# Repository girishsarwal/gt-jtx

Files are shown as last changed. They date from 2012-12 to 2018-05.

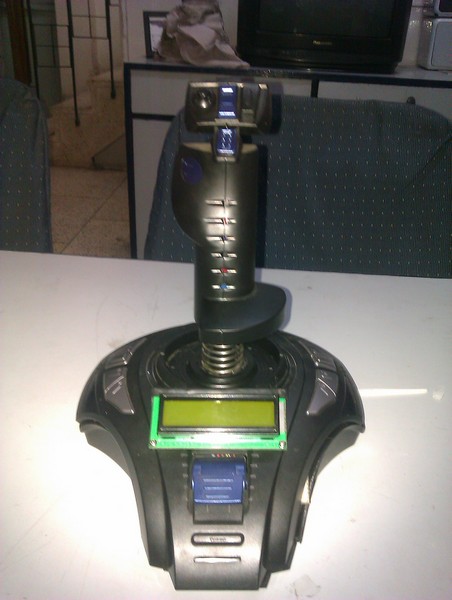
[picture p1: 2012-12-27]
gt-jtx-m8/build-photos/IMAG0161.jpg

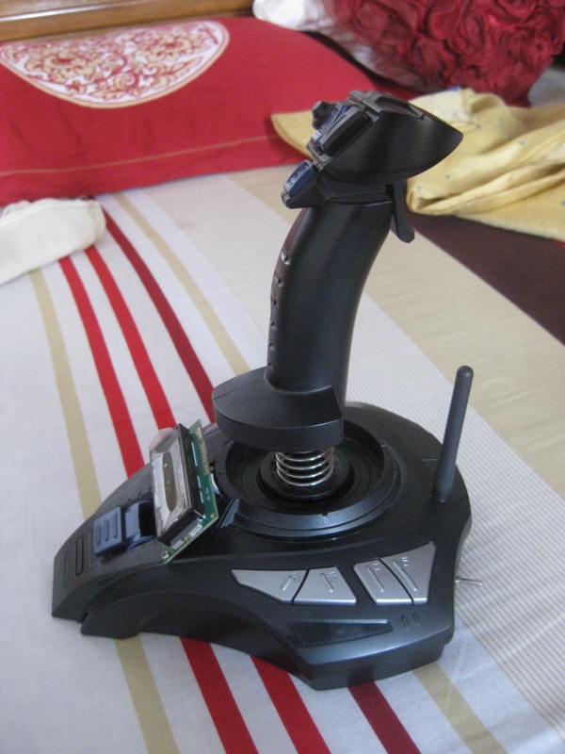
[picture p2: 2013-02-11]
gt-jtx-m8/build-photos/IMG_1433.JPG

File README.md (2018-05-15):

# gt-jtx
What is gt-jtx?
I feel it's cool to control an airplane with a 3d joystick rather than gimbals. It's intuitive and real aircraft pilots (or those trained on MSFS) can appreciate. See Yoke and HOTAS ("Hotass")

After a good amount of self provocation, I embarked on the journey of doing a joystick based 4 analog and 1 digital channels transmitter for controlling Airplanes. Additionally, this system needs to have a basic menu system, settings (Expo/Dr, Rev etc..) and a monitor

# How does it work?
The gt-jtx uses a 3d joystick for controlling an RC airplane. The X axis map to ailerons (roll), Y to Elevator (pitch) and the joystick grip twist/Z axis map to Rudder (Yaw) control. The throttle control has a separate pot on the base of the joystick. Digital push buttons 5-12 on the joystick base are trim switches for the four channels and pressing unique combos on these switches along with power switch navigates through the menu and settings screen.

# Variants
There are three variants of the gt-jtx in order of ease of development

- Arduino Mega - V1.2 available - Open TX
- ATMEGA 8 - V1.0 available - Custom firmware
- ATMEGA 32 - Work under progress

See the wiki for more details

# Disclaimer
I take no responsibility or warranty for any damage to you or your equipment, that may arise out of or is a consequence of using or reproducing any parts or features of the gt-jtx software/hardware system. Everything you do is completely at your own risk and expense.

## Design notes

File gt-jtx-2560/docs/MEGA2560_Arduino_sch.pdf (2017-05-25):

ICSP

# +5V GND

+5V

GND

GND

+5V

GND | GND
47u | 47u GND | GND

GND

GND

GREEN | GND
+5V M7 | GND MC33269D-5.0 MC33269ST-5.0T3

100nGND
100n

100n

+3V3

+5V

+5V

ATMEGA1280-16AU

100n 100n

22p

+5V

GND

100n GND

100n

YELLOW

YELLOW

500mA

+5V

100n GND

YELLOW

GND

100n

FDN340P

LM358D | LM358D GND

100n GND

+5V

100n | +5V

GND

+5V

GND

1u

+5V

ATMEGA8U2-MU

ICSP

+5V

GND

GND

16MHz GND | GND
BLM21 PGB¹⁰¹⁰⁶⁰⁴ | PGB¹⁰¹⁰⁶⁰⁴

16MHz GND
1M

1k

1k

1k

1k

10K

10K 10K

10K

10K

10K

10K

10K

1k1k

1k1k

22R

22R
22R

22R

GND
TS42

1M

16MHz

16MHz

22p 22p

22p 22p GND

GND

GND

27R

27R

1 | 2
3 | 4
5 | 6

ICSP

1

2

3

4

5

6

7

8 | PWML

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
PWMH

PC1 | PC2 | ON D1
1

1

2

2

3

3 | VI 3

1 VO

2

IC2 ADJ

1

IN

3 OUT

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
POWER

C3 | C6

C2

1

2

3

4

5

91 | | 7
92 | ADC0 ADC2 ADC1 ADC3 ADC4 ADC5 ADC6 ADC7 | 6
8 | ADCL

1

2

3

4

5

6

7

8 | COMMUNICATION

(A8)PC0

53

(A9)PC1

54

(A10)PC2

55

(A11)PC3

56

(A12)PC4

57

(A13)PC5

58

(A14)PC6

59

(A15)PC7

60

(AD0)PA0

78

(AD1)PA1

77

(AD2)PA2

76

(AD3)PA3

75

(AD4)PA4

74

(AD5)PA5

73

(AD6)PA6

72

(AD7)PA7

71

(ADC0)PF0

97

(ADC1)PF1

96

(ADC2)PF2

95

(ADC3)PF3

94

(ADC4/TCK)PF4

93

(ADC5/TMS)PF5

(ADC6/TDO)PF6

(ADC7/TDI)PF7

90

(ALE)PG2

70

(CLKO/ICP3/INT7)PE7

9

(ICP1)PD4

47

(MISO/PCINT3)PB3

22
(MOSI/PCINT2)PB2

21

(OC0A/OC1C/PCINT7)PB7

26

(OC0B)PG5

1

(OC1A/PCINT5)PB5

24

(OC1B/PCINT6)PB6

25

(OC2A/PCINT4)PB4

23

(OC3A/AIN1)PE3

5

(OC3B/INT4)PE4

6

(OC3C/INT5)PE5

7

(RD)PG1

52

(RXD0/PCIN8)PE0

2

(RXD1/INT2)PD2

45

(SCK/PCINT1)PB1

20

(SCL/INT0)PD0

43

(SDA/INT1)PD1

44

(SS/PCINT0)PB0

19

(T0)PD7

50
(T1)PD6

49

(T3/INT6)PE6

8

(TOSC1)PG4

29
(TOSC2)PG3

28

(TXD0)PE1

3

(TXD1/INT3)PD3

46

(WR)PG0

51

(XCK0/AIN0)PE2

4

(XCK1)PD5

48

AGND

99 | AREF
98 | AVCC
100

GND

11
32
62
81
PH0(RXD2) 12 | PH1(TXD2) 13 | PH2(XCK2) 14 | PH3(OC4A) 15 | PH4(OC4B) 16 | PH5(OC4C) 17 | PH6(OC2B) 18 | PH7(T4) 27 | PJ0(RXD3/PCINT9) 63 | PJ1(TXD3/PCINT10) 64 | PJ2(XCK3/PCINT11) 65 | PJ3(PCINT12) 66 | PJ4(PCINT13) 67 | PJ5(PCINT14) 68 | PJ6(PCINT15) 69 | PJ7
79 | PK0(ADC8/PCINT16) 89 | PK1(ADC9/PCINT17) 88 | PK2(ADC10/PCINT18) 87 | PK3(ADC11/PCINT19) 86 | PK4(ADC12/PCINT20) 85 | PK5(ADC13/PCINT21) 84 | PK6(ADC14/PCINT22) 83 | PK7(ADC15/PCINT23) 82 | PL0(ICP4) 35 | PL1(ICP5) 36 | PL2(T5) 37 | PL3(OC5A) 38 | PL4(OC5B) 39 | PL5(OC5C) 40 | PL6
41 | PL7

42

RESET

30

VCC

10
31
61
80

XTAL1

34 XTAL2

33

GND GND GND

VCC

VCC

VCC

IC3

C4 C5

1

2

3

4

5

6

7

8 ADCH

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
$1 P$1 P$2 P$2 X2 F1

C9

L

C7

T2

2

3
1

IC5A

6

5
7

IC5B

8 4
C12 C11
1 | 2
3 | 4
5 | 6
7 | 8
9 | 10
11 | 12
13 | 14
15 | 16

XIOH

1 | 2
3 | 4
5 | 6
7 | 8
9 | 10
11 | 12
13 | 14
15 | 16

XIOL

1 | JP1
1 | JP2
1 | JP3
1 | JP4
1 | 2 RESET-EN

C10

(PCINT9/OC1B)PC5

25
(PCINT10)PC4

26

(INT4/ICP1/CLK0)PC7

22
(OC1A/PCINT8)PC6

23

(AIN2/PCINT11)PC2

5

(PCINT5)PB5

19
(T1/PCINT4)PB4

18
(PD0/MISO/PCINT3)PB3

17
(PDI/MOSI/PCINT2)PB2

16
(SCLK/PCINT1)PB1

15
(SS/PCINT0)PB0

14

(CTS/HWB/AIN6/TO/INT7)PD7

13
(RTS/AIN5/INT6)PD6

12
(XCK/AIN4/PCINT12)PD5

11
(INT5/AIN3)PD4

10
(TXD1/INT3)PD3

9
(RXD1/AIN1/INT2)PD2

8
(AIN0/INT1)PD1

7
(OC0B/INT0)PD0

6

GND

3 | VCC
4 | AVCC

32

UVCC

31

XTAL1

1 | XTAL2(PC0) 2 | RESET(PC1/DW) 24

UGND

28

IC4

PAD

EXP

UCAP

27 | D- 30 | D+

29

(PCINT6)PB6

20

(PCINT7/OC0A/OC1C)PB7

21

1 | 2
3 | 4
5 | 6

ICSP1

Y2

## 2 1 UBOOT

L1

Z1Z2

1 2 GROUND

Y1 R1

1 | 8 RN4A
2 | 7 RN4B
3 | 6 RN4C
4 | 5 RN4D

### 1 8 RN5A

2 7 RN5B

3 6 RN5C

4 5 RN5D

1 8 RN1A

2 7 RN1B

3 6 RN1C

4 | 5 RN1D
1 | 8 RN3A
2 | 7 RN3B
3 | 6 RN3C
5 | 4 RN3D
8 | 1 RN2A
2 | 7 RN2B
3 | 6 RN2C
5 | 4 RN2D
3 | 1
4 | 2 RESET

5

R2

2 1Q1

2 1Q2

C14 C15

C16 C17

IN

1 | EN
3 | NC/FB

4 OUT

5 GND

2

R3

R4

+5V
+5V

GND

AREF AREF AREF

RESET

RESET | RESET

RESET

RESET

VIN

VIN

VIN

# M8RXD M8RXD M8TXD

M8TXD

PWRIN

+3V3

+3V3 | +3V3

SDA

SDA

SCL

SCL ADC9 ADC8 ADC10 ADC11 ADC12 ADC13 ADC14 ADC15

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
PB5 PB4

PE5 | PE5 PE4 | PE4 PE3 | PE3 PE1 | PE1

PE1

PE0 | PE0 | PE0

DTR

USBVCC

USBVCC

USBVCC GATE_CMD

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
RXD1 TXD1 RXD2

RXD2

RXD3

RXD3

TXD2

TXD2

TXD3

TXD3

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
## PB0 PG0

PG0

PG1

PG1

PG2

PG2

PD7 PD7

PA0 | PA0 PA1 | PA1 PA2 | PA2 PA3 | PA3 PA4 | PA4 PA5 | PA5 PA6 | PA6 PA7 | PA7
PL0 PL0 | PL1 PL1 | PL2 PL2 | PL3 PL3 | PL4 PL4 | PL5 PL5 | PL6 PL6 | PL7 PL7

PB7

VUCAP

RD-

RD-

RD+

RD+

RESET2

RESET2 | MISO2

MISO2

MOSI2

MOSI2

SCK2

SCK2

XVCC

RXL TXL

# D- D+ UGND

UGND

USHIELD

XTAL2

XTAL2 XTAL1

XTAL1

XT2

## XT2 XT1

XT1

XTAL1R

XT1R

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
(SCK)

(MISO)
(MOSI)

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
(TX0)
(RX0)

51

53 | 52

pwm
pwm

pwm

pwm
pwm

(MISO)

(SCK)

(MOSI)

(SS)
(MOSI)

(SCK)
(MISO)
23 | 22
25 | 24
27 | 26
29 | 28
| 30

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
USB boot En

# Arduino Mega 2560 Reference Design

TM

Reference Designs ARE PROVIDED "AS IS" AND "WITH ALL FAULTS". Arduino DISCLAIMS ALL OTHER WARRANTIES, EXPRESS OR IMPLIED, Arduino may make changes to specifications and product descriptions at any time, without notice. The Customer must not REGARDING PRODUCTS, INCLUDING BUT NOT LIMITED TO, ANY IMPLIED WARRANTIES OF MERCHANTABILITY OR FITNESS FOR A PARTICULAR PURPOSE

rely on the absence or characteristics of any features or instructions marked "reserved" or "undefined." Arduino reserves
these for future definition and shall have no responsibility whatsoever for conflicts or incompatibilities arising from future changes to them. The product information on the Web Site or Materials is subject to change without notice. Do not finalize a design with this information.

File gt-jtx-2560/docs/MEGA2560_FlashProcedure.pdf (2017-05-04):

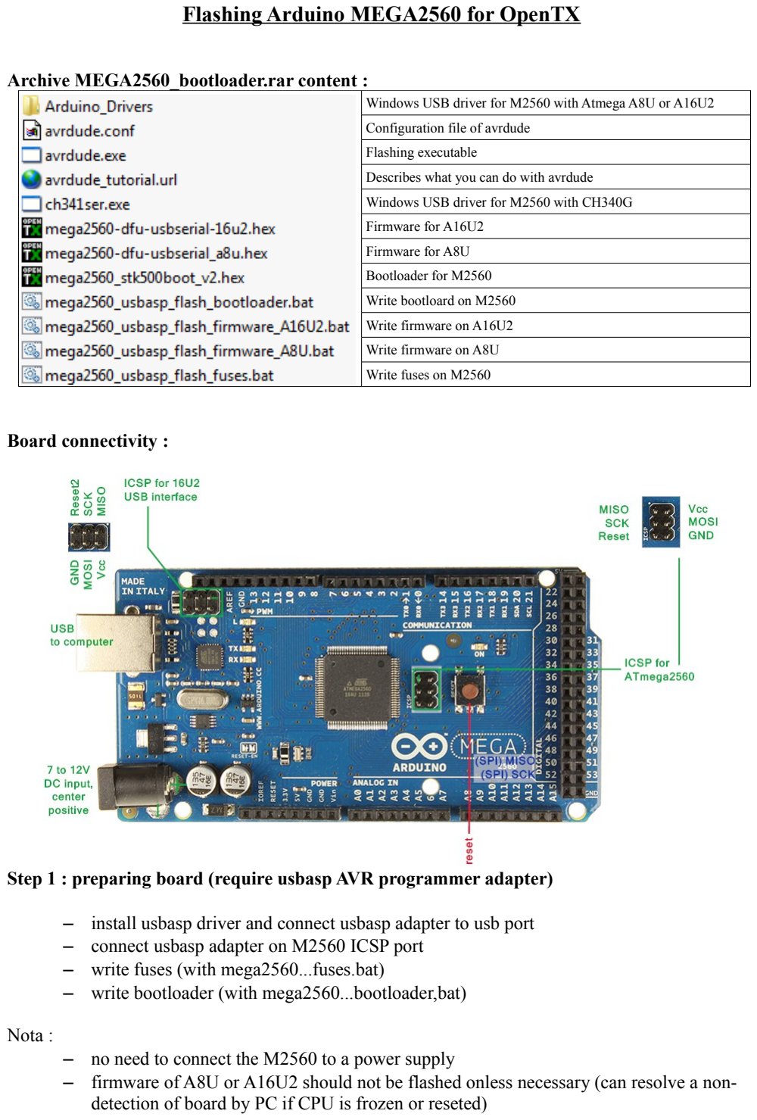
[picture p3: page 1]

Flashing Arduino MEGA2560 for OpenTX

Archive MEGA2560_bootloader.rar content :
Windows USB driver for M2560 with Atmega A8U or A16U2 Configuration file of avrdude
Flashing executable
Describes what you can do with avrdude
Windows USB driver for M2560 with CH340G Firmware for A16U2
Firmware for A8U
Bootloader for M2560
Write bootloard on M2560
Write firmware on A16U2
Write firmware on A8U
Write fuses on M2560

Board connectivity :

Step 1 : preparing board (require usbasp AVR programmer adapter)

– install usbasp driver and connect usbasp adapter to usb port – connect usbasp adapter on M2560 ICSP port
– write fuses (with mega2560...fuses.bat)
– write bootloader (with mega2560...bootloader,bat)

Nota :
– no need to connect the M2560 to a power supply
– firmware of A8U or A16U2 should not be flashed onless necessary (can resolve a nondetection of board by PC if CPU is frozen or reseted)

Step 2 : connecting board to USB
CH340G board | A8U or A16U2 board
- execute « ch341ser.exe » to install driver • connect M2560 on one USB port • Windows should automatically configure driver | • connect M2560 on one USB port • Windows opens an installation panel • choose manually the driver « arduino.inf » in the folder « Arduino_Drivers » provided

– verify on Windows device management (direct access : devmgmt.msc) if device works, and witch com is used (com1, com2, etc.)

Step 3 : setting Companion communication

– launch OpenTX Companion 2.1
– open the « Configure communications » menu
– set the following parameters (with the right com) :

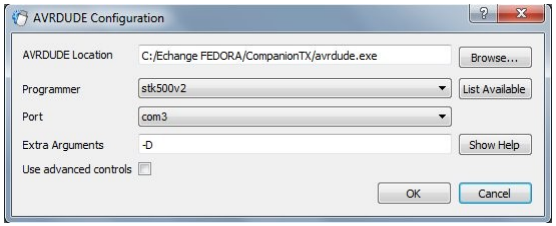
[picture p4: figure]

– A8U or A16U2 board : for each firmware or eeprom access (read or flash), M2560 must be reset just before (press reset button is board is already connected, or simply plug the board on USB)
– CH340G board : USB communication remains open after startup, no need to reset
Step 3 : setting Companion Radio Profile and and Application Settings

– go to the « Settings » menu, click « Settings »
– select « Radio Profile » tab
– check LCD, language and options needed :

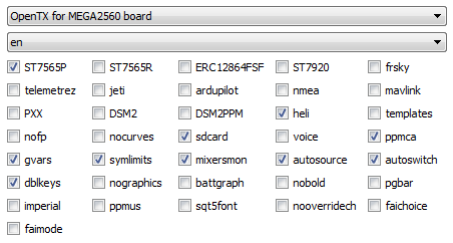
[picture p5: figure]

– select « Application Settings » tab
– open a folder for eeprom backup (don't check « Enable auto... » for the moment)
Step 4 : first flash with Companion

– go to « File » menu, click « Download »
– download firmware
– go to « Read/Write » menu, click « Write Firmware to Radio »
– load the downloaded firmware
– uncheck (for the moment) « Backup and restore Models ans Settings »

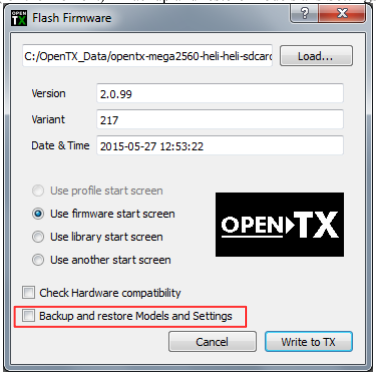
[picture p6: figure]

– write to TX...
– unplug the radio form USB port
– run the radio or plug it to usb port
– OpenTX should start and launch the init sequence (formatting eeprom then calibrate the sticks)
– enjoy... :)

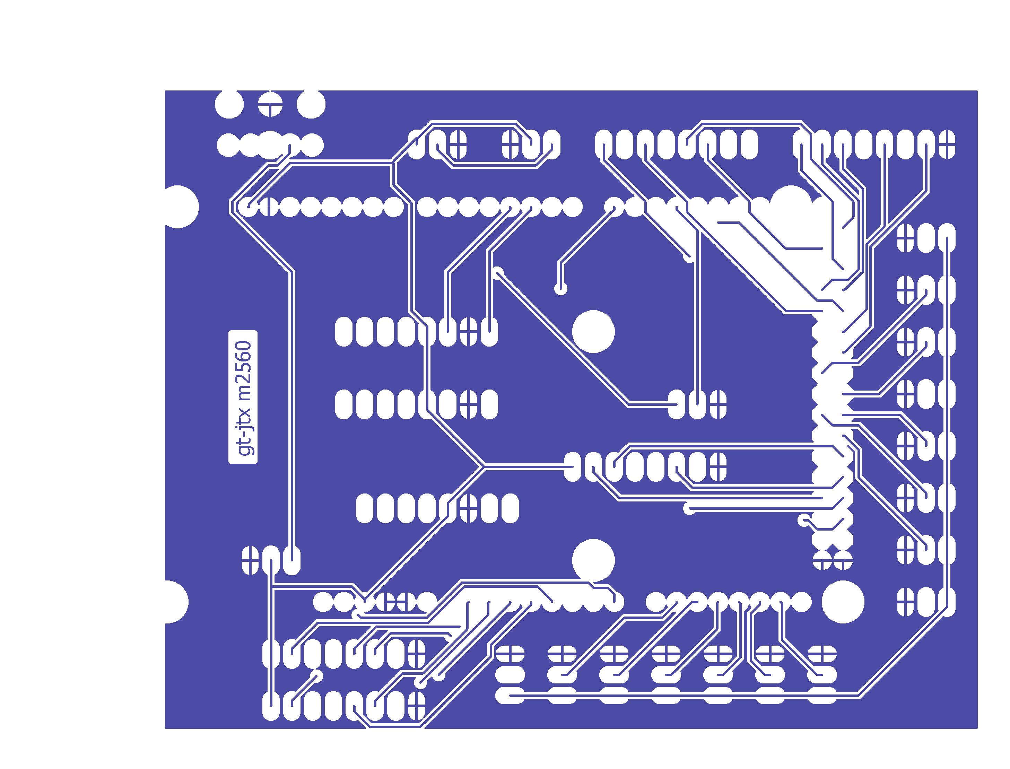
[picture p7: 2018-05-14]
gt-jtx-2560/hardware/bottom.png

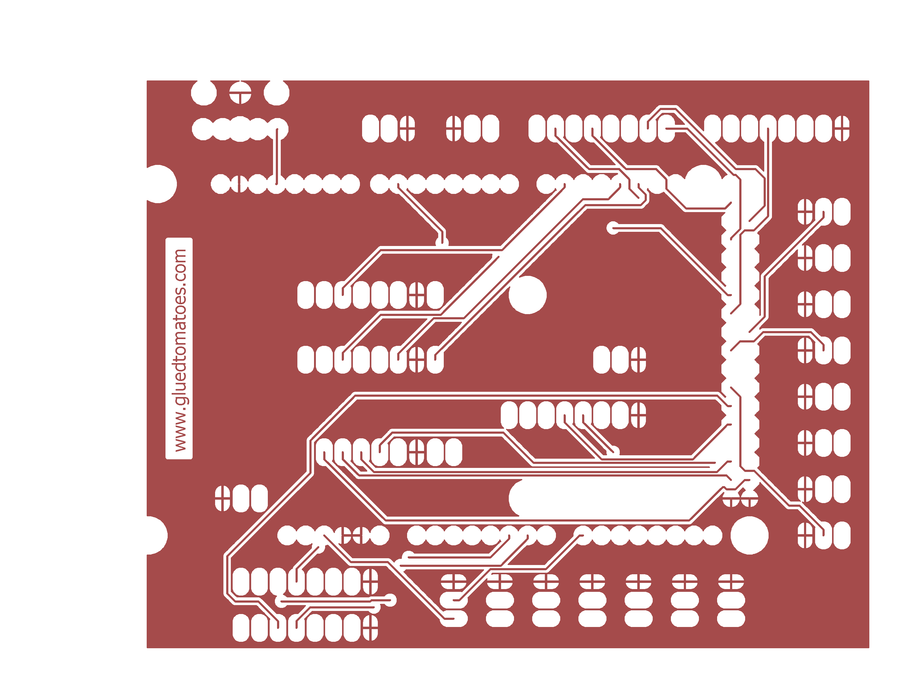
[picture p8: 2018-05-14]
gt-jtx-2560/hardware/top.png

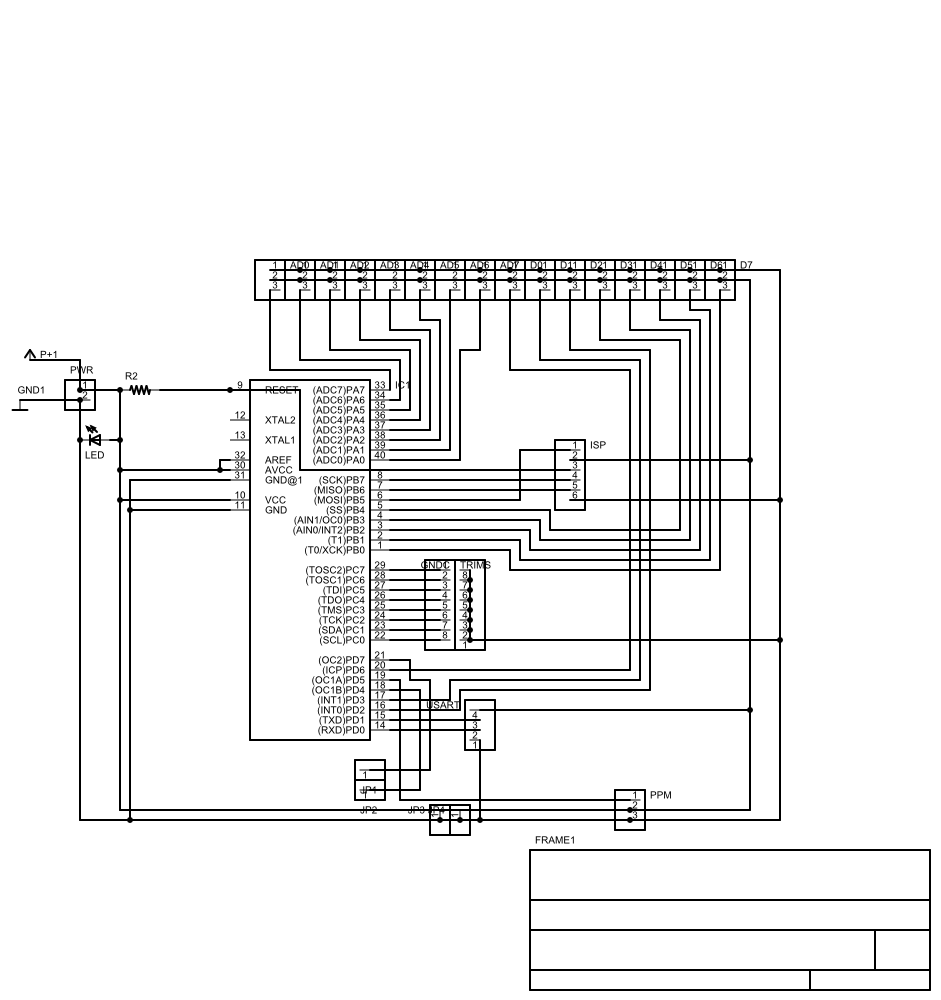
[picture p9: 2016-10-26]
gt-jtx-m32/hardware/gt-jtx-m32-ver1.0.png

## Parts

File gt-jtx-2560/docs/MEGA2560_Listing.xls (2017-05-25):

Board | Label | Qty | Manufacturer | Part Number | Description | Case | Implantation | Side | Points | Total pts | Comment
- | - | 1 | - | - | 2 mm plywood 250 x 500 mm | - | - | - | - | - | Prefere marine or aircraft plywood
- | - | 1 | Funduino, SaintSmart | MEGA2560 | Arduino Mega2560 clone (http://www.ebay.fr/itm/291335218312) | - | - | - | - | - | Main board (prefer with CH340G serial driver) (http://www.ebay.fr/itm/151303481964)
- | - | 2 | Samsung, Panasonic, etc. | - | 18650 round Li-Ion with PCB (http://fr.aliexpress.com/item/-/32257563308.html) | - | - | - | - | - | 2400 to 3400 mAh
- | - | 1 | - | - | HF module (2.4 GHz, 433 MHz, etc.) | - | - | - | - | - | PPM positive or negative shift, up to 16 channels + telemetry
- | - | 0 to 1 | - | - | RS232 to TTL converter (MAX3232) (http://www.ebay.fr/itm/221484714177) | - | - | - | - | - | For FrSky telemetry (if no "direct TTL" modification)
- | - | 1 | - | - | USBASP programmer (http://www.ebay.com/sch/i.html?_from=R40&_nkw=usbasp&_sacat=0) | - | - | - | - | - | For bootloader and fuses flash
- | - | 1 | Artronic | 128064MN19-FHW | LCD 128x64 ST7565R (http://www.ebay.fr/itm/321632747032) | - | - | - | - | - | LCD (large, 3.3V, to use with M2560-1 board)
- | - | 1 | Zolen | ZLE12864A | LCD 128x64 ST7565P (http://fr.aliexpress.com/item/4pcs-New-12864-128x64-Graphic-LCD-Display-module-ST7565P-Free-Shipping/1383335383.html) | - | - | - | - | - | LCD (small, 5V)
- | - | 1 | Turnigy | 9171000250 | 9XR gimbal left (http://www.hobbyking.com/hobbyking/store/__39505__transmitter_gimbal_set_left_turnigy_9xr_transmitter_mode_1.html) | - | - | - | - | - | Gimbal basic (direct connection on MEGA)
- | - | 1 | Turnigy | 9171000248 | 9XR gimbal right (http://www.hobbyking.com/hobbyking/store/__39503__Transmitter_Gimbal_Set_Right_Turnigy_9XR_Transmitter_Mode_1.html) | - | - | - | - | - | Gimbal basic (direct connection on MEGA)
- | - | 2 | Hitec | - | Aurora9 gimbal (http://www.robotshop.com/en/axis-joystick-gim.html) | - | - | - | - | - | Gimbal option (to use with M2560-5 board)
 | - | 0 to 2 | - | - | PS2 gimbal (http://www.aliexpress.com/item/Free-Shipping-20PCS-LOT-Dual-axis-XY-Joystick-Module-For-Arduino-ps2-Joystick-Module/1882818018.html) | - | - | - | - | - | Gimbal option
- | - | 1 | Turnigy | 9171000045 | M3 sticks pair (http://www.hobbyking.com/hobbyking/store/__23754__Alloy_Anti_Slip_TX_Control_Sticks_Short_Futaba_TX_.html) | - | - | - | - | - | Fit basic or option gimbal
- | - | 0 to 1 | - | - | on-off-on switch | - | - | - | - | - | ID0/1/2 switch
- | - | 0 to 5 | - | - | off-on switch | - | - | - | - | - | DR_e, DR_a, DR_r, ThCut, Gear switches
- | - | 0 to 1 | - | - | off-(on) switch | - | - | - | - | - | TRN (momentary, classic switch)
- | - | 0 to 1 | APEM | MJTP1230 | SPST tactile switch | - | - | - | - | - | TRN (momentary, small swtich), or other(s) switch(es) with T flip-flop virtual switch
- | - | 1 | ALPS | SKQUAAA010 | 4 way navigation switch | - | - | - | - | - | 4 way navigation (if no scroll navigation with M2560-1&2 boards)
- | - | 0 or 2 | APEM | MJTP1230 | SPST tactile switch | - | - | - | - | - | OK/ESC buttons (if no scroll navigation with M2560-1&2 boards)
- | - | 3 | - | - | JST BEC female connector plug | - | - | - | - | - | Charge or external supply connecteur + internal power wiring
- | - | 1 | - | - | JST BEC male connector plug | - | - | - | - | - | Internal power wiring
- | SW1 | 1 | Multicomp | R13-548B-05-BB | SPST push-button | - | - | - | - | - | Main power swtitch (basic)
- | SW1 | 1 | - | - | SPST metal + led push-button (http://www.ebay.fr/sch/i.html?_from=R40&_sacat=0&_nkw=metal+led+switch&_sop=15) | - | - | - | - | - | Main power swtitch (option)
- | - | 0.5 m | - | - | 28 or 30 AWG flap ribbon cable, 20 wires | - | - | - | - | - | LCD, switches and rotary encoders wiring
- | - | 1 | DB Products | PK-21N30-WQ | Piezoelectronic buzzer | - | - | - | - | - | Buzzer with built-in drive circuit
- | - | 0 to 1 | - | - | Mini SD-Card socket for Arduino (http://www.ebay.fr/itm/221485468743) | - | - | - | - | - | Option
- | - | 0 to 1 | - | - | Real Time Clock (http://www.ebay.fr/itm/251730989006) | - | - | - | - | - | Option
M2560-1_LCD | Q1 | 1 | ON Semiconductor | MMFT960T1 | 300 mA 60 Volts N−Channel MOSFET | SOT-223 | SMD | Top | 4 | 4
M2560-1_LCD | U3 | 1 | Microchip | MCP1826S3302 | 3.3V 1A Low drop positive regulator | SOT-223 | SMD | Top | 4 | 4
M2560-1_LCD | R4 | 14 | - | - | 5.1 Kohms 1% resistor | 1206 | SMD | Top | 2 | 28
M2560-1_LCD | R6 | 14 | - | - | 10 Kohms 1% resistor | 1206 | SMD | Top | 2 | 28
M2560-1_LCD | C1 | 2 | - | - | 100 nF 10% 63 V Capacitor X7R | 1206 | SMD | Top | 2 | 4
M2560-2_RotEnc1 | - | 1 | C&K | TSWB-3N-CB111 LFS | 4 ways navigation switch + scroll + pushbutton | - | Through hole | Bottom | 9 | 9 | Rotary encoder 1 & navigation (arrows + Menu)
M2560-2_RotEnc1 | R1 | 7 | - | - | 200 ohms 1% resistor | 1206 | SMD | Top | 2 | 14
M2560-2_RotEnc1 | R4 | 2 | - | - | 5.1 Kohms 1% resistor | 1206 | SMD | Top | 2 | 4
M2560-2_RotEnc1 | C1 | 7 | - | - | 100 nF 10% 63 V Capacitor X7R | 1206 | SMD | Top | 2 | 14
M2560-3_RotEnc2 | - | 1 | C&K | TSWA-3N-CB11 LFS | Scroll + pushbutton | - | Through hole | Bottom | 4 | 4 | Rotary encoder 2 & navigation (Esc) or alone rotary (Rot_x + Push_x)
M2560-3_RotEnc2 | R1 | 3 | - | - | 200 ohms 1% resistor | 1206 | SMD | Top | 2 | 6
M2560-3_RotEnc2 | R4 | 2 | - | - | 5.1 Kohms 1% resistor | 1206 | SMD | Top | 2 | 4
M2560-3_RotEnc2 | C1 | 3 | - | - | 100 nF 10% 63 V Capacitor X7R | 1206 | SMD | Top | 2 | 6
M2560-4_Trim&switches | - | 2 | ALPSS | SKQUAAA01 | 4 ways navigation swtich | - | Through hole | Bottom | 6 | 12
M2560-4_Trim&switches | R1 | 8 | - | - | 200 ohms 1% resistor | 1206 | SMD | Top | 2 | 16
M2560-4_Trim&switches | C1 | 8 | - | - | 100 nF 10% 63 V Capacitor X7R | 1206 | SMD | Top | 2 | 16
M2560-5_Sticks(basic) | - | 4 | TE Connectivity | 292161-3 | 2 mm 3 pins connector header | - | Through hole | Bottom | 3 | 12
M2560-5_Sticks(basic) | - | 1 | - | - | 2.54 mm connector header | - | Through hole | Top | 4 | 4 | 4 pins
M2560-5_Sticks(basic) | U2 | 1 | Microchip | MCP6004 | Low-Power Op Amp | SOIC-14 | SMC | Top | 14 | 14
M2560-5_Sticks(basic) | R2 | 4 | - | - | 2.2 Kohms 1% resistor | 1206 | SMD | Top | 2 | 8
M2560-5_Sticks(basic) | R6 | 8 | - | - | 10 Kohms 1% resistor | 1206 | SMD | Top | 2 | 16
M2560-5_Sticks(full) | - | 4 | TE Connectivity | 292161-3 | 2 mm 3 pins connector header | - | Through hole | Bottom | 3 | 12
M2560-5_Sticks(full) | - | 1 | - | - | 2.54 mm connector header | - | Through hole | Top | 4 | 4 | 21 pins
M2560-5_Sticks(full) | U2 | 1 | Microchip | MCP6004 | Low-Power Op Amp | SOIC-14 | SMC | Top | 14 | 14
M2560-5_Sticks(full) | R2 | 4 | - | - | 2.2 Kohms 1% resistor | 1206 | SMD | Top | 2 | 8
M2560-5_Sticks(full) | R3 | 1 | - | - | 2.7 Kohms 1% resistor | 1206 | SMD | Top | 2 | 2
M2560-5_Sticks(full) | R4 | 1 | - | - | 5.1 Kohms 1% resistor | 1206 | SMD | Top | 2 | 2
M2560-5_Sticks(full) | R6 | 8 | - | - | 10 Kohms 1% resistor | 1206 | SMD | Top | 2 | 16
M2560-6_PPM&Power | - | 1 | - | - | 2.54 mm connector header | - | Through hole | Bottom | 4 | 4 | 33 pins
M2560-6_PPM&Power | U1 | 1 | On Semiconductor | MC14066B | Quad multiplexer | SOIC-14 | SMD | Top | 14 | 14 | Trainer port selector (in / out)
M2560-6_PPM&Power | Q1 | 1 | ON Semiconductor | MMFT960T1 | 300 mA 60 Volts N−Channel MOSFET | SOT-223 | SMD | Top | 4 | 4
M2560-6_PPM&Power | Q2 | 1 | Fairchild Semicon. | NDT2955 | 2.5 A 60 Volts P−Channel MOSFET | SOT-223 | SMD | Top | 4 | 4
M2560-6_PPM&Power | D1 | 4 | MCC | MBR0520LT1G | 0.5 A 20 V low drop Schottky | SOD-123 | SMD | Top | 2 | 8
M2560-6_PPM&Power | R1 | 1 | - | - | 200 ohms 1% resistor | 1206 | SMD | Top | 2 | 2
M2560-6_PPM&Power | R3 | 1 | - | - | 2.7 Kohms 1% resistor | 1206 | SMD | Top | 2 | 2
M2560-6_PPM&Power | R4 | 5 | - | - | 5.1 Kohms 1% resistor | 1206 | SMD | Top | 2 | 10
M2560-6_PPM&Power | R5 | 2 | - | - | 6.8 Kohms 1% resistor | 1206 | SMD | Top | 2 | 4
M2560-6_PPM&Power | R6 | 2 | - | - | 10 Kohms 1% resistor | 1206 | SMD | Top | 2 | 4
M2560-6_PPM&Power | R7 | 2 | - | - | 100 Kohms 1% resistor | 1206 | SMD | Top | 2 | 4
M2560-6_PPM&Power | C1 | 1 | - | - | 100 nF 10% 63 V Capacitor X7R | 1206 | SMD | Top | 2 | 2
M2560-6_PPM&Power | SW2 | 1 | CUI Inc | MD-40SV | Mini DIN 4 pins socket | - | - | - | - | - | Trainer port
M2560-6_PPM&Power | SW2 | 1 | CUI Inc | MD-40 | Mini DIN 4 pins plug | - | - | - | - | - | Trainer port

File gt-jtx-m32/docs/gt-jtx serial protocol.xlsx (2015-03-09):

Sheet: Sheet1
SYNC | PID | SIZE | PAYLOAD

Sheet: Sheet2
Data Signal
OpCode | Description | Data |  | Result
0x00 | Error |  | 8 x 1
0x01 | Frame Lengths |  | 16 x 2
0x02 | Servo Signal Timing |  | 16 x 2
0x03 | Calibration Data Upper |  | 16 x 14
0x04 | Calibration Data Lower |  | 16 x 14
0x05
0x06
0x07
0x08
0x09
0x10 | Pot Data |  | 16 x 14
0x11 | Trim Data |  | 16 x 14
0x12 | Ch Reverse Data |  | 1 x 14
0x13 | Expo Data |  | 16 x 14
0x14 | D/R Data |  | 16 x 14
0x15 | Offset Data |  | 8 x 14
0x16
0x17
0x18
0x19
0x20
0x21
0x22
0x23
0x24
0x25
0x26
0x27
0x28
0x29
0x30
0x31
0x32
0x33
0x34
0x35
0x36
0x37
0x38
0x39
0x40

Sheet: SPI Protocol for UI comms
 | 15 | 14 | 13 | 12 | 11 | 10 | 9 | 8 | 7 | 6 | 5 | 4 | 3 | 2 | 1 | 0
OpCode | Data0 |  |  |  |  |  |  |  | Data1 |  |  |  |  |  |  |  | Result | Menmonic | Description | Comment | General Instructions
0x00 | X |  |  |  |  |  |  |  | X |  |  |  |  |  |  |  | X | NOP | Nop |  | Each SPI Command sends 4 bytes SPI xchange
0x01 | Ch# |  |  |  | X | X | X | X | Amount |  |  |  |  |  |  |  | X | SETTUP | SetTrimUp | Amount is clamped to 200 | the first byte is the opcode
0x02 | Ch# |  |  |  | X | X | X | X | Amount |  |  |  |  |  |  |  | X | SETTDN | SetTrimDn | Amount is clamped to 200 | The second and third byte together form the data for the instruction
0x03 | Ch# |  |  |  | X | X | X | X | Result-HiByte |  |  |  |  |  |  |  | Result-LoByte | GETT | Get Trim | Gets the trim in Amount | The final byte is always a NOP to get the lower byte of the result
0x04 | Ch# |  |  |  | B | X | X | X | X | X | X | X | X | X | X | X | X | SETREV | SetReverse | B=1(REV); B=0(NOR)
0x05 | Ch# |  |  |  | B | X | X | X | Result-HiByte |  |  |  |  |  |  |  | Result-LoByte | GETREV | GetReverse | B=1(REV); B=0(NOR) | Bytes | OpCode | Data0 | Data1 | Result
0x06 | Ch# |  |  |  | X | X | Amount |  |  |  |  |  |  |  |  |  | X | SCUP | SetCalibrationUpper |  | SPI Sent | Opcode | Data0 | Data1 | NOP
0x07 | Ch# |  |  |  | X | X |  |  | Result-HiByte |  |  |  |  |  |  |  | Result-LoByte | GCUP | GetCalibrationUpper |  | SPI Received | NOP | Opcode | Data0 | Data1
0x08 | Ch# |  |  |  | X | X | Amount |  |  |  |  |  |  |  |  |  | X | SCDN | SetCalibrationLower
0x09 | Ch# |  |  |  | X | X |  |  | Result-HiByte |  |  |  |  |  |  |  | Result-LoByte | GCDN | GetCalibrationLower
0x0A | Amount |  |  |  |  |  |  |  |  |  |  |  |  |  |  |  | X | SPPMLEN | SetPPMFrameTotalLength | Amount is in ms
0x0B |  |  |  |  |  |  |  |  | Result-HiByte |  |  |  |  |  |  |  | Result-LoByte | GPPMLEN | GetPPMFrameTotalLength | Amount is in ms
0x0C | Amount |  |  |  |  |  |  |  |  |  |  |  |  |  |  |  | X | SPPMICL | SetPPMFrameInterChannelLength | Amount is in us
0x0D |  |  |  |  |  |  |  |  | Result-HiByte |  |  |  |  |  |  |  | Result-LoByte | GPPMICL | GetPPMFrameInterChannelLength | Amount is in us
0x0E | B | Amount |  |  |  |  |  |  |  |  |  |  |  |  |  |  | X | SSTIM | SetServoTiming | B=0(Lower);B=1(Upper)
0x0F | B |  |  |  |  |  |  |  | Result-HiByte |  |  |  |  |  |  |  | Result-LoByte | GSTIM | GetServoTiming | B=0(Lower);B=1(Upper)
0x10 | Ch# |  |  |  |  |  |  |  | Result-HiByte |  |  |  |  |  |  |  | Result-LoByte | GCV | GetChannelValue

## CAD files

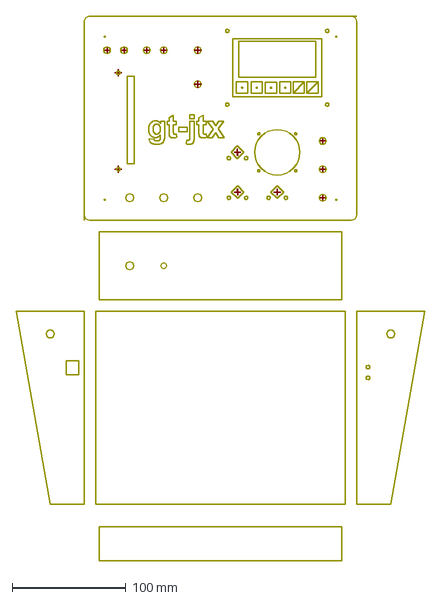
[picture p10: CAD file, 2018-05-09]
gt-jtx-2560/case/gt-jtx-2560.dxf
360.0 x 480.0 mm

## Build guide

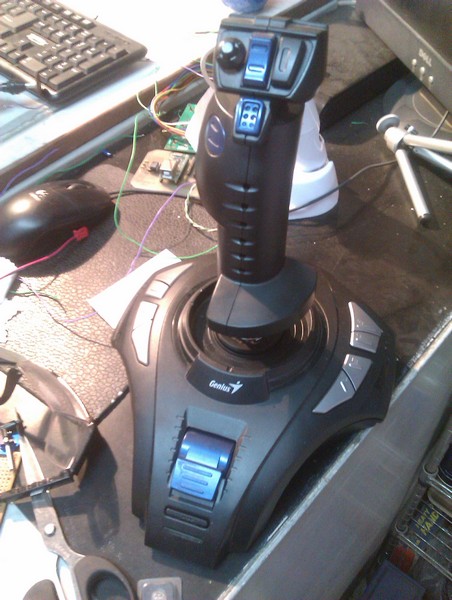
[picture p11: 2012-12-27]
gt-jtx-m8/build-photos/IMAG0158.jpg

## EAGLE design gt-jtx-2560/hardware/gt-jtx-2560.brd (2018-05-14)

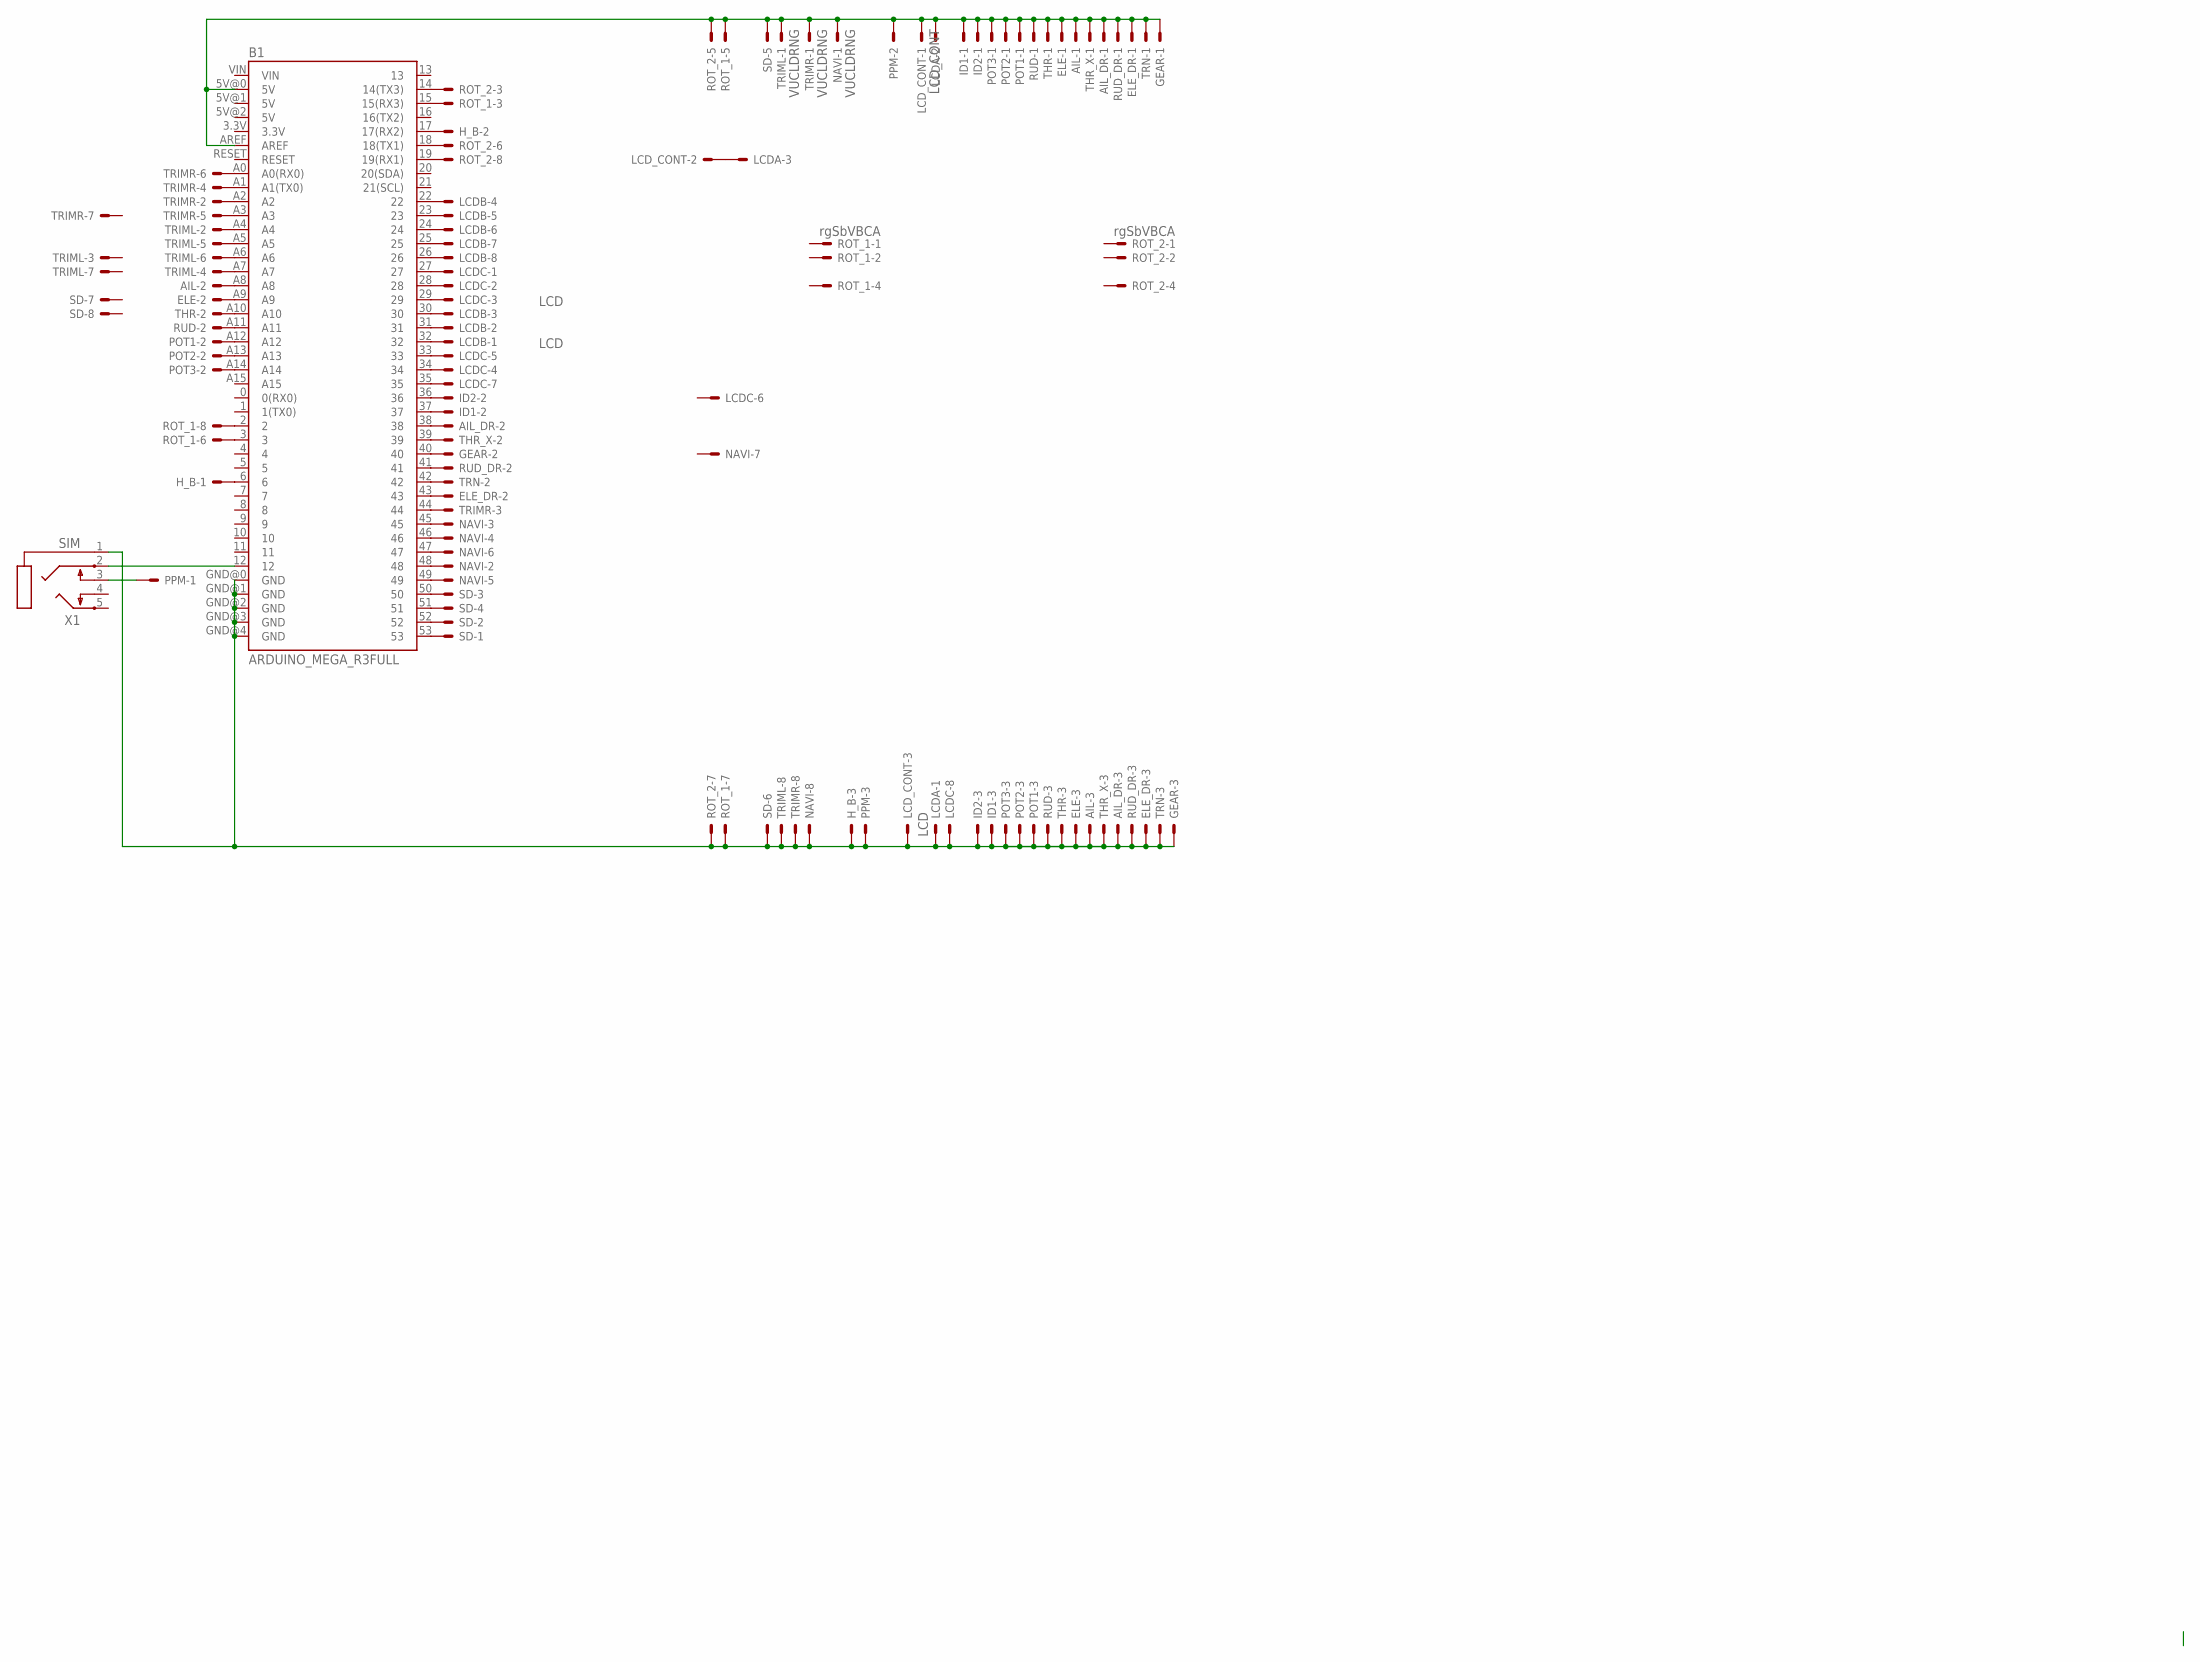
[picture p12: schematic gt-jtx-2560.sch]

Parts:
AIL: JST-XH-03-PIN-LONG-PAD; JST-XH-03-PACKAGE-LONG-PAD
AIL_DR: JST-XH-03-PIN-LONG-PAD; JST-XH-03-PACKAGE-LONG-PAD
B1: ARDUINO_MEGA_R3FULL; ARDUINO_MEGA
ELE: JST-XH-03-PIN-LONG-PAD; JST-XH-03-PACKAGE-LONG-PAD
ELE_DR: JST-XH-03-PIN-LONG-PAD; JST-XH-03-PACKAGE-LONG-PAD
GEAR: JST-XH-03-PIN-LONG-PAD; JST-XH-03-PACKAGE-LONG-PAD
H_B: JST-XH-03-PIN-LONG-PAD; JST-XH-03-PACKAGE-LONG-PAD
ID1, ID2: JST-XH-03-PIN-LONG-PAD; JST-XH-03-PACKAGE-LONG-PAD
LCDA: LCD; JST-XH-03-PACKAGE-LONG-PAD
LCDB: LCD; JST-XH-08-PACKAGE-LONG-PAD
LCDC: LCD; JST-XH-08-PACKAGE-LONG-PAD
LCD_CONT: LCD_CONT; JST-XH-03-PACKAGE-LONG-PAD
NAVI: VUCLDRNG; JST-XH-08-PACKAGE-LONG-PAD
POT1, POT2, POT3: JST-XH-03-PIN-LONG-PAD; JST-XH-03-PACKAGE-LONG-PAD
PPM: JST-XH-03-PIN-LONG-PAD; JST-XH-03-PACKAGE-LONG-PAD
ROT_1, ROT_2: rgSbVBCA; JST-XH-08-PACKAGE-LONG-PAD
RUD: JST-XH-03-PIN-LONG-PAD; JST-XH-03-PACKAGE-LONG-PAD
RUD_DR: JST-XH-03-PIN-LONG-PAD; JST-XH-03-PACKAGE-LONG-PAD
SD: JST-XH-08-PIN-LONG-PAD; JST-XH-08-PACKAGE-LONG-PAD
THR: JST-XH-03-PIN-LONG-PAD; JST-XH-03-PACKAGE-LONG-PAD
THR_X: JST-XH-03-PIN-LONG-PAD; JST-XH-03-PACKAGE-LONG-PAD
TRIML: VUCLDRNG; JST-XH-08-PACKAGE-LONG-PAD
TRIMR: VUCLDRNG; JST-XH-08-PACKAGE-LONG-PAD
TRN: JST-XH-03-PIN-LONG-PAD; JST-XH-03-PACKAGE-LONG-PAD
X1: SIM; STX3100

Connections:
GND: AIL.3, AIL_DR.3, B1.GND@0 (GND), B1.GND@1 (GND), B1.GND@2 (GND), B1.GND@3 (GND), B1.GND@4 (GND), ELE.3, ELE_DR.3, GEAR.3, H_B.3, ID1.3, ID2.3, LCDA.1, LCDC.8, LCD_CONT.3, NAVI.8, POT1.3, POT2.3, POT3.3, PPM.3, ROT_1.7, ROT_2.7, RUD.3, RUD_DR.3, SD.6, THR.3, THR_X.3, TRIML.8, TRIMR.8, TRN.3, X1.1
unnamed: B1.22, LCDB.4
unnamed: B1.23, LCDB.5
unnamed: B1.24, LCDB.6
unnamed: B1.25, LCDB.7
unnamed: B1.26, LCDB.8
unnamed: B1.27, LCDC.1
unnamed: B1.28, LCDC.2
unnamed: B1.29, LCDC.3
unnamed: B1.48, NAVI.2
unnamed: B1.45, NAVI.3
unnamed: B1.46, NAVI.4
unnamed: B1.49, NAVI.5
unnamed: B1.47, NAVI.6
unnamed: B1.A2, TRIMR.2
unnamed: B1.A7, TRIML.4
unnamed: B1.53, SD.1
unnamed: B1.A5, TRIML.5
unnamed: B1.44, TRIMR.3
unnamed: AIL.2, B1.A8
unnamed: B1.A9, ELE.2
unnamed: B1.A10, THR.2
unnamed: B1.A11, RUD.2
unnamed: B1.A12, POT1.2
unnamed: B1.A13, POT2.2
unnamed: B1.A14, POT3.2
unnamed: B1.52, SD.2
unnamed: B1.A1 (A1(TX0)), TRIMR.4
unnamed: B1.A3, TRIMR.5
unnamed: B1.50, SD.3
unnamed: B1.51, SD.4
unnamed: B1.15 (15(RX3)), ROT_1.3
unnamed: B1.6, H_B.1
unnamed: B1.39, THR_X.2
unnamed: B1.41, RUD_DR.2
unnamed: B1.43, ELE_DR.2
unnamed: AIL_DR.2, B1.38
unnamed: B1.42, TRN.2
unnamed: B1.40, GEAR.2
unnamed: B1.12, X1.2
unnamed: B1.17 (17(RX2)), H_B.2
unnamed: B1.A0 (A0(RX0)), TRIMR.6
unnamed: B1.30, LCDB.3
unnamed: B1.31, LCDB.2
unnamed: B1.A6, TRIML.6
unnamed: B1.A4, TRIML.2
unnamed: B1.14 (14(TX3)), ROT_2.3
unnamed: B1.2, ROT_1.8
unnamed: B1.3, ROT_1.6
unnamed: B1.19 (19(RX1)), ROT_2.8
unnamed: B1.18 (18(TX1)), ROT_2.6
unnamed: B1.32, LCDB.1
unnamed: B1.34, LCDC.4
unnamed: B1.33, LCDC.5
unnamed: B1.35, LCDC.7
unnamed: LCDA.3, LCD_CONT.2
unnamed: PPM.1, X1.3
unnamed: B1.36, ID2.2
unnamed: B1.37, ID1.2
VCC: AIL.1, AIL_DR.1, B1.5V@0 (5V), B1.AREF, ELE.1, ELE_DR.1, GEAR.1, ID1.1, ID2.1, LCDA.2, LCD_CONT.1, NAVI.1, POT1.1, POT2.1, POT3.1, PPM.2, ROT_1.5, ROT_2.5, RUD.1, RUD_DR.1, SD.5, THR.1, THR_X.1, TRIML.1, TRIMR.1, TRN.1

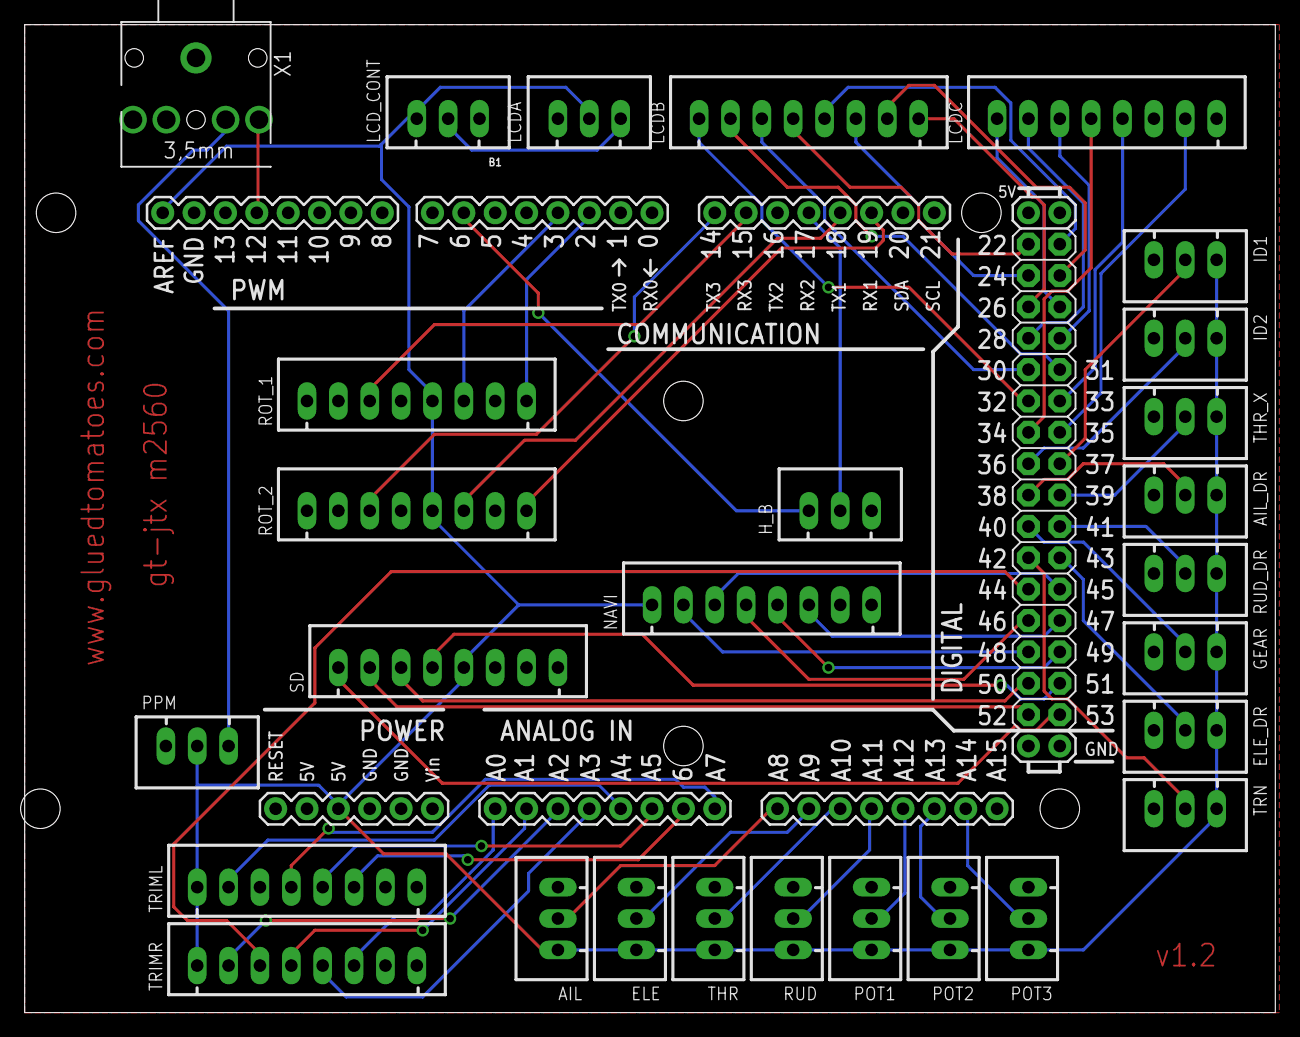
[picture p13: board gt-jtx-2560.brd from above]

Board: 2 copper layers, 101.3 x 80.0 mm, 29 parts (0 on the bottom side), 60 nets.

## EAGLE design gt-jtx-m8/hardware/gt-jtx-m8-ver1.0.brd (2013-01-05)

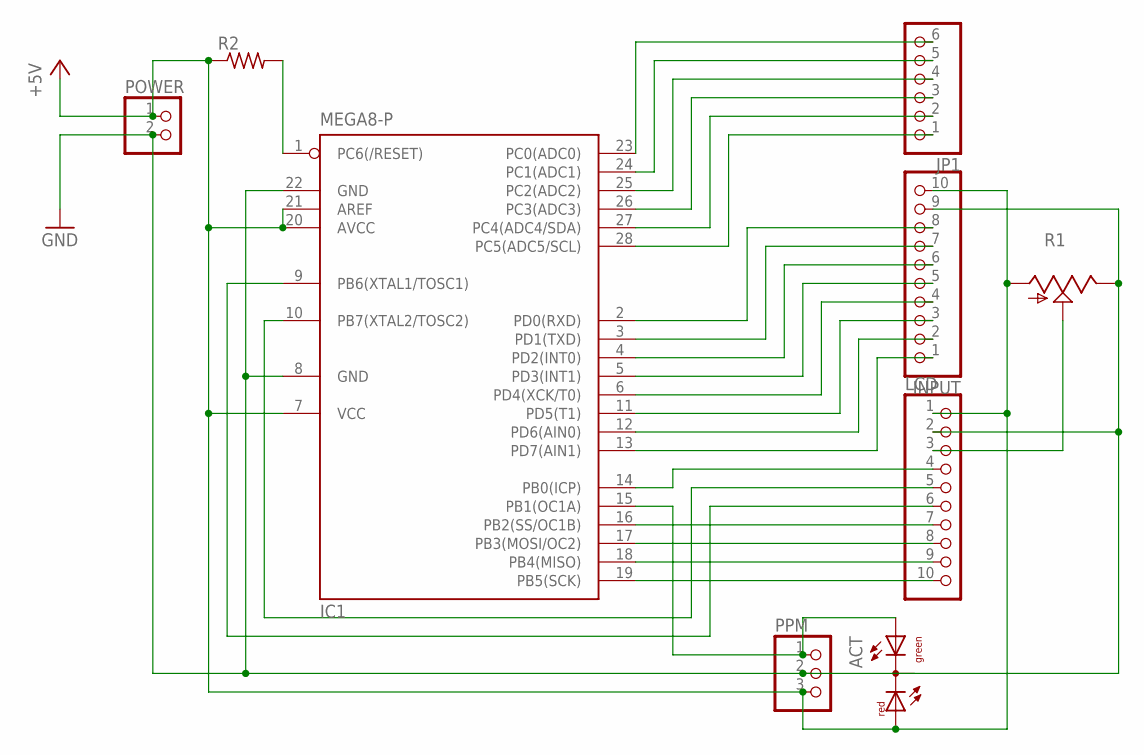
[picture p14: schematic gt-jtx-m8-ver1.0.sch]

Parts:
ACT: DUOLED-RG-C; DUOLED-C-5MM
IC1: MEGA8-P; DIL28-3
INPUT: PINHD-1X10; 1X10
JP1: PINHD-1X6; 1X06
LCD: PINHD-1X10; 1X10
POWER: PINHD-1X2; 1X02
PPM: PINHD-1X3; 1X03
R1: TRIM_US-CA6V; CA6V
R2: R-US_0204/2V; 0204V

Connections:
+5V: ACT.AR, IC1.7 (VCC), IC1.20 (AVCC), IC1.21 (AREF), INPUT.10, LCD.1, POWER.1, PPM.3, R1.A, R2.1
GND: ACT.C, IC1.8 (GND), IC1.22 (GND), INPUT.9, LCD.2, POWER.2, PPM.2, R1.E
unnamed: IC1.23 (PC0(ADC0)), JP1.6
unnamed: IC1.24 (PC1(ADC1)), JP1.5
unnamed: IC1.25 (PC2(ADC2)), JP1.4
unnamed: IC1.26 (PC3(ADC3)), JP1.3
unnamed: IC1.14 (PB0(ICP)), LCD.4
unnamed: IC1.10 (PB7(XTAL2/TOSC2)), LCD.5
unnamed: IC1.9 (PB6(XTAL1/TOSC1)), LCD.6
unnamed: IC1.2 (PD0(RXD)), INPUT.8
unnamed: LCD.3, R1.S
unnamed: IC1.27 (PC4(ADC4/SDA)), JP1.2
unnamed: IC1.28 (PC5(ADC5/SCL)), JP1.1
unnamed: IC1.19 (PB5(SCK)), LCD.10
unnamed: IC1.18 (PB4(MISO)), LCD.9
unnamed: IC1.17 (PB3(MOSI/OC2)), LCD.8
unnamed: IC1.16 (PB2(SS/OC1B)), LCD.7
unnamed: ACT.AX (AG), IC1.15 (PB1(OC1A)), PPM.1
unnamed: IC1.3 (PD1(TXD)), INPUT.7
unnamed: IC1.4 (PD2(INT0)), INPUT.6
unnamed: IC1.5 (PD3(INT1)), INPUT.5
unnamed: IC1.6 (PD4(XCK/T0)), INPUT.4
unnamed: IC1.11 (PD5(T1)), INPUT.3
unnamed: IC1.13 (PD7(AIN1)), INPUT.1
unnamed: IC1.12 (PD6(AIN0)), INPUT.2
unnamed: IC1.1 (PC6(/RESET)), R2.2

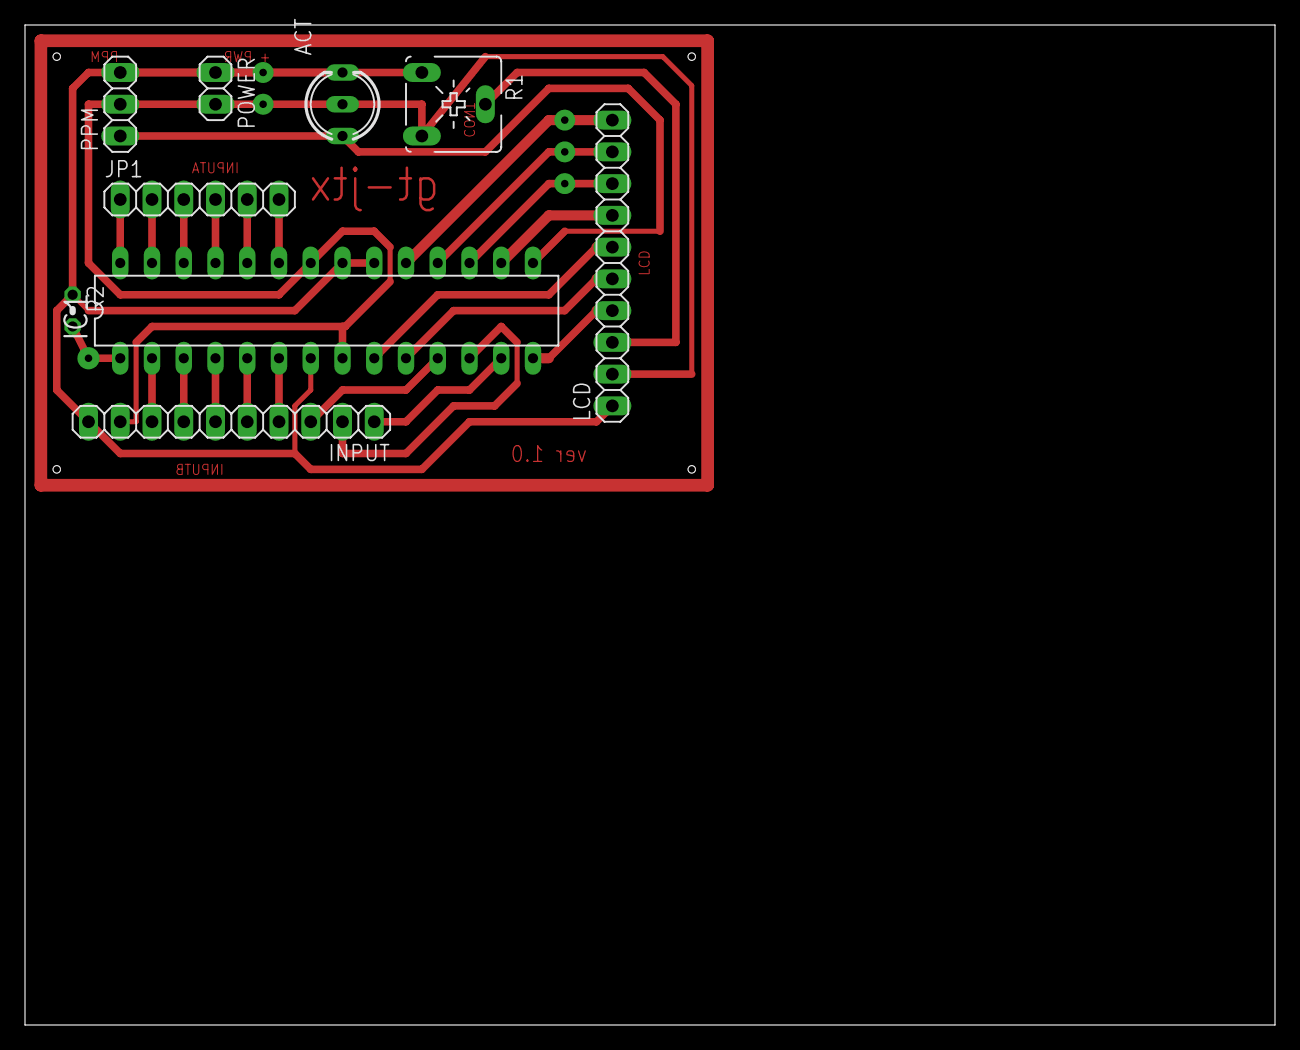
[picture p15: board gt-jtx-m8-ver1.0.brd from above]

Board: 2 copper layers, 100.0 x 80.0 mm, 9 parts (0 on the bottom side), 26 nets.

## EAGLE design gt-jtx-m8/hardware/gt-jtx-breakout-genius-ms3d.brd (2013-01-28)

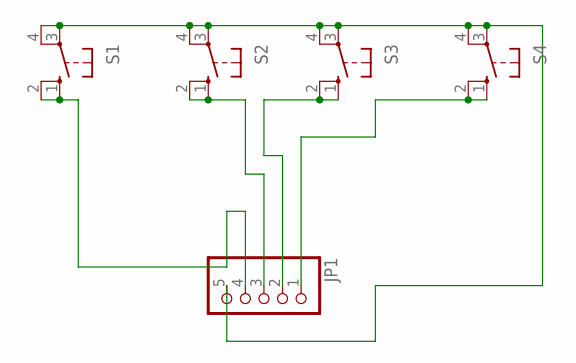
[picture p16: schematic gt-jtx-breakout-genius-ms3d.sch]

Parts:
JP1: PINHD-1X5; 1X05
S1, S2, S3, S4: 10-XX; B3F-10XX

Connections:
GND: JP1.5, S1.3, S1.4 (P1), S2.3, S2.4 (P1), S3.3, S3.4 (P1), S4.3, S4.4 (P1)
unnamed: JP1.2, S3.1 (S), S3.2 (S1)
unnamed: JP1.1, S4.1 (S), S4.2 (S1)
unnamed: JP1.4, S1.1 (S), S1.2 (S1)
unnamed: JP1.3, S2.1 (S), S2.2 (S1)

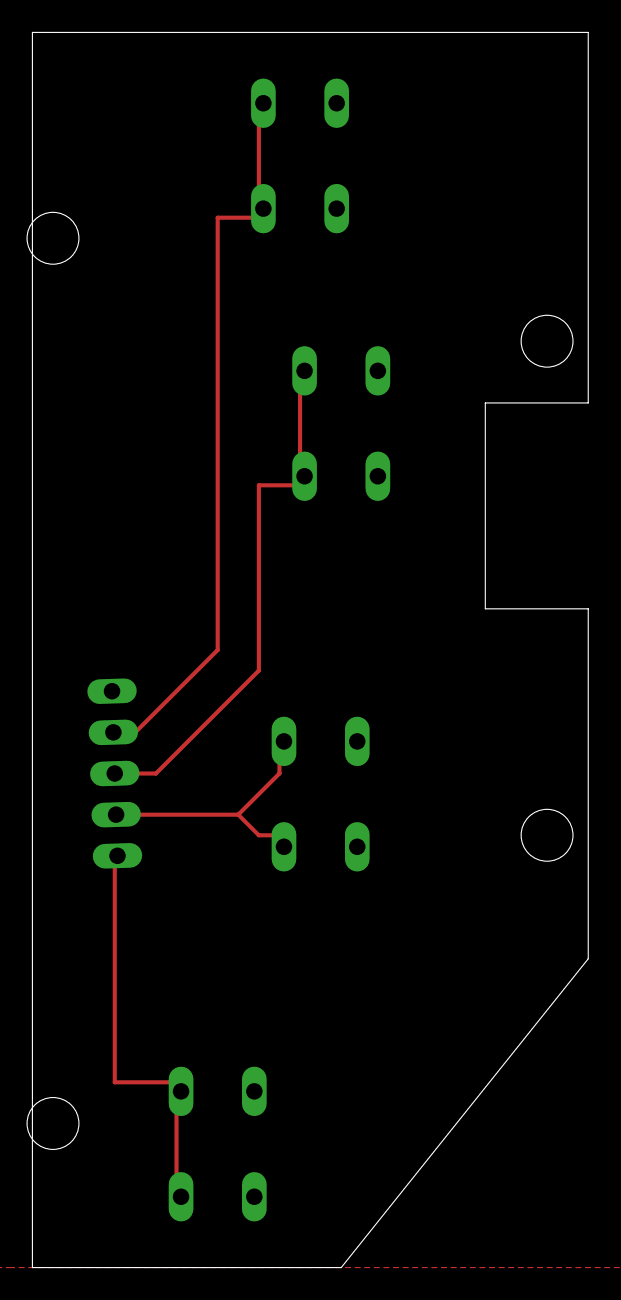
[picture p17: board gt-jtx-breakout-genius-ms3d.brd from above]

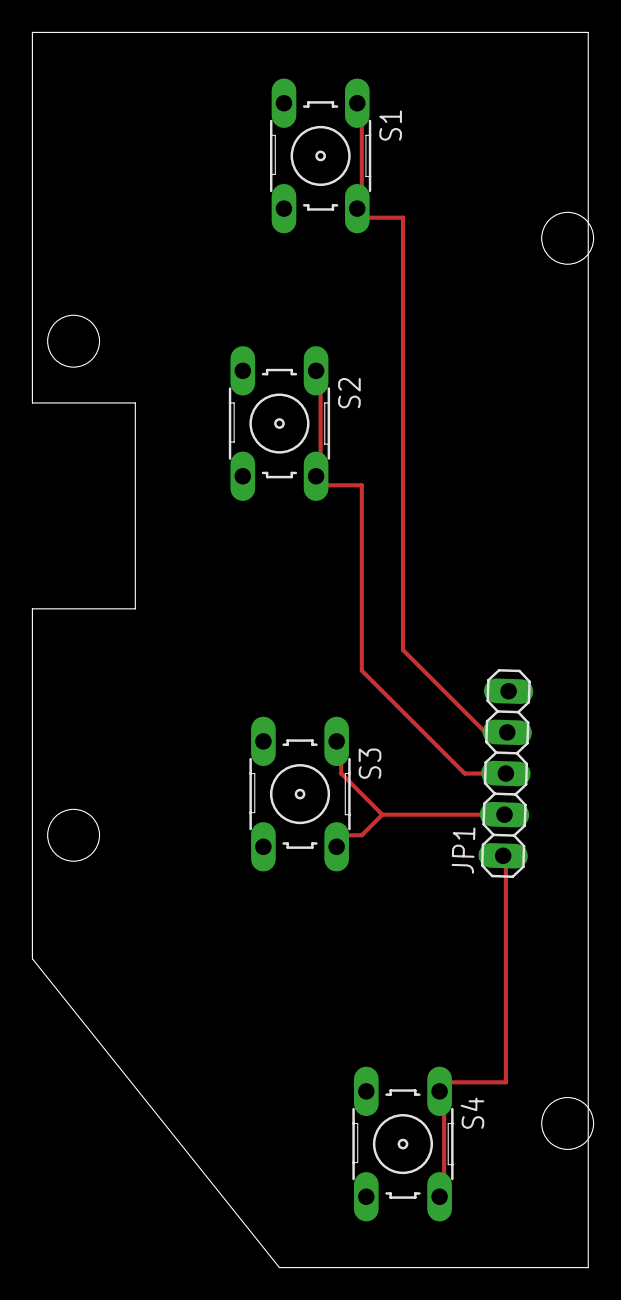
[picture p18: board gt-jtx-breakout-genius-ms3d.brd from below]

Board: 2 copper layers, 34.3 x 76.2 mm, 5 parts (5 on the bottom side), 5 nets.

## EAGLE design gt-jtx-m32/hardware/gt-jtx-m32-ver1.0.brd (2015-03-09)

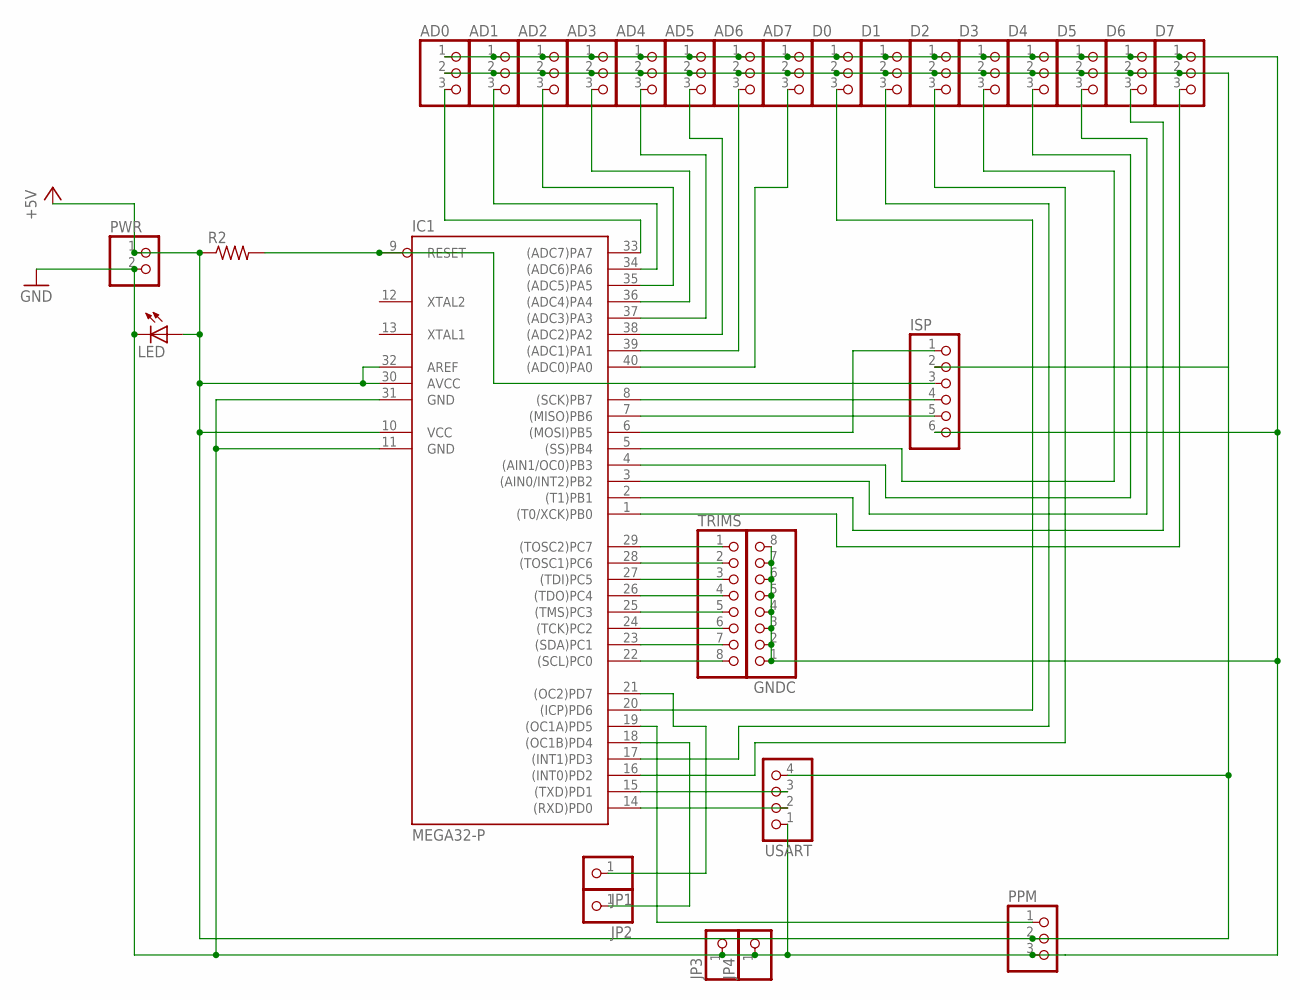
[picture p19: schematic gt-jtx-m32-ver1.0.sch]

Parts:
AD0, AD1, AD2, AD3, AD4, AD5, AD6, AD7: PINHD-1X3; 1X03
D0, D1, D2, D3, D4, D5, D6, D7: PINHD-1X3; 1X03
GNDC: PINHD-1X8; 1X08
IC1: MEGA32-P; DIL40
ISP: PINHD-1X6; 1X06
JP1, JP2, JP3, JP4: PINHD-1X1; 1X01
LED: LED5MM
PPM: PINHD-1X3; 1X03
PWR: PINHD-1X2; 1X02
R2: R-US_0204/2V; 0204V
TRIMS: PINHD-1X8; 1X08
USART: PINHD-1X4; 1X04

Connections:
+5V: AD0.2, AD1.2, AD2.2, AD3.2, AD4.2, AD5.2, AD6.2, AD7.2, D0.2, D1.2, D2.2, D3.2, D4.2, D5.2, D6.2, D7.2, IC1.10 (VCC), IC1.30 (AVCC), IC1.32 (AREF), ISP.2, LED.A, PPM.2, PWR.1, R2.1, USART.4
GND: AD0.1, AD1.1, AD2.1, AD3.1, AD4.1, AD5.1, AD6.1, AD7.1, D0.1, D1.1, D2.1, D3.1, D4.1, D5.1, D6.1, D7.1, GNDC.1, GNDC.2, GNDC.3, GNDC.4, GNDC.5, GNDC.6, GNDC.7, GNDC.8, IC1.11 (GND), IC1.31 (GND), ISP.6, JP3.1, JP4.1, LED.K (C), PPM.3, PWR.2, USART.1
unnamed: AD7.3, IC1.40 ((ADC0)PA0)
unnamed: AD6.3, IC1.39 ((ADC1)PA1)
unnamed: AD5.3, IC1.38 ((ADC2)PA2)
unnamed: AD4.3, IC1.37 ((ADC3)PA3)
unnamed: IC1.14 ((RXD)PD0), USART.2
unnamed: IC1.15 ((TXD)PD1), USART.3
unnamed: IC1.29 ((TOSC2)PC7), TRIMS.1
unnamed: AD3.3, IC1.36 ((ADC4)PA4)
unnamed: IC1.9 (RESET), ISP.3, R2.2
unnamed: AD2.3, IC1.35 ((ADC5)PA5)
unnamed: AD1.3, IC1.34 ((ADC6)PA6)
unnamed: IC1.6 ((MOSI)PB5), ISP.1
unnamed: IC1.7 ((MISO)PB6), ISP.5
unnamed: IC1.8 ((SCK)PB7), ISP.4
unnamed: IC1.19 ((OC1A)PD5), PPM.1
unnamed: IC1.28 ((TOSC1)PC6), TRIMS.2
unnamed: AD0.3, IC1.33 ((ADC7)PA7)
unnamed: IC1.27 ((TDI)PC5), TRIMS.3
unnamed: IC1.26 ((TDO)PC4), TRIMS.4
unnamed: IC1.25 ((TMS)PC3), TRIMS.5
unnamed: IC1.24 ((TCK)PC2), TRIMS.6
unnamed: IC1.23 ((SDA)PC1), TRIMS.7
unnamed: IC1.22 ((SCL)PC0), TRIMS.8
unnamed: D3.3, IC1.5 ((SS)PB4)
unnamed: D4.3, IC1.4 ((AIN1/OC0)PB3)
unnamed: D5.3, IC1.3 ((AIN0/INT2)PB2)
unnamed: D6.3, IC1.2 ((T1)PB1)
unnamed: D7.3, IC1.1 ((T0/XCK)PB0)
unnamed: D2.3, IC1.16 ((INT0)PD2)
unnamed: D1.3, IC1.17 ((INT1)PD3)
unnamed: D0.3, IC1.20 ((ICP)PD6)
unnamed: IC1.18 ((OC1B)PD4), JP2.1
unnamed: IC1.21 ((OC2)PD7), JP1.1

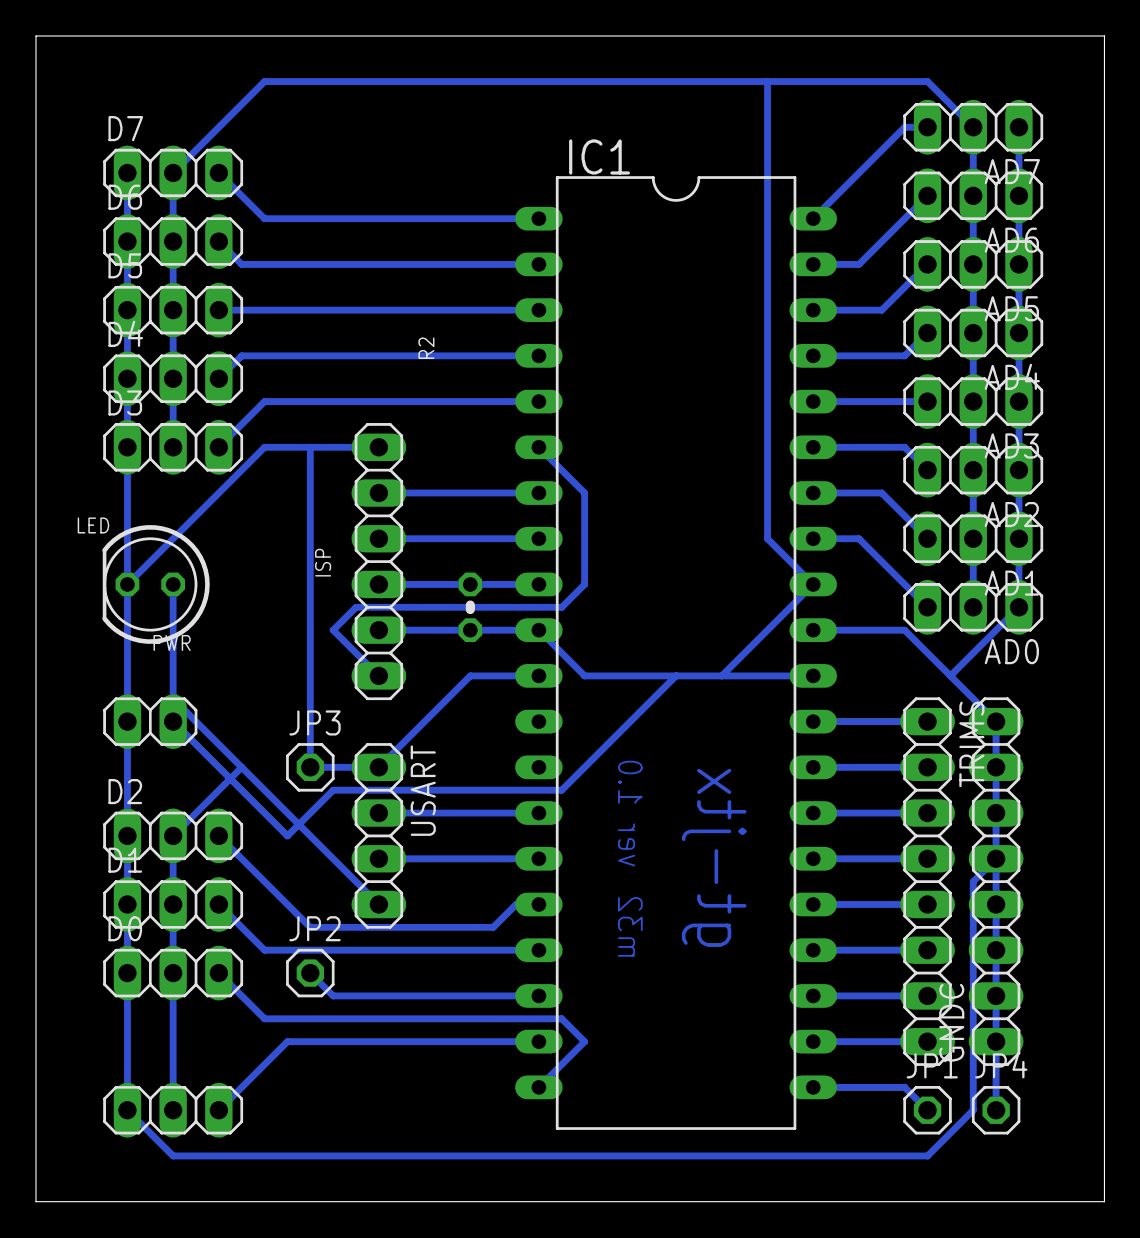
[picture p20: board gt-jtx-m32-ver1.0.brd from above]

Board: 2 copper layers, 59.4 x 64.8 mm, 29 parts (0 on the bottom side), 35 nets.

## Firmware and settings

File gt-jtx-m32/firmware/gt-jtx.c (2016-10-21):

/*
 * gt-jtx.cpp
 *	
 *  Author: Girish Sarwal
 *	 Email: g.sarwal@gmail.com
 *       , girish.sarwal@gluedtomatoes.com
 *
 */
#ifndef F_CPU
#define F_CPU 1000000UL
#endif

#define DEBUG

#include <avr/io.h>
#include <util/delay.h>
#include <avr/eeprom.h>
#include <avr/interrupt.h>
#include <math.h>

#define INP1		0    //Mapped to PA7
#define INP2		1    //Mapped to PA6
#define INP3		2    //Mapped to PA5
#define INP4		3    //Mapped to PA4
#define INP5 		4    //Mapped to PA3
#define INP6		5    //Mapped to PA2
#define INP7		6    //Mapped to PA1
#define INP8		7    //Mapped to PA0

#define MAX_ANALOG_INPUTS 8

#define INP9		8     //Mapped to PD6
#define INP10		9     //Mapped to PD3
#define INP11		10    //Mapped to PD2
#define INP12		11    //Mapped to PB4
#define INP13		12    //Mapped to PB3
#define INP14		13    //Mapped to PB2
#define INP15		14    //Mapped to PB1
#define INP16		15     //Mapped to PB0

#define MAX_DIGITAL_INPUTS 8

#define PIN0		0
#define PIN1		1
#define PIN2		2
#define PIN3		3
#define PIN4		4
#define PIN5		5
#define PIN6		6
#define PIN7		7

#define NUM_PHYSICAL_INPUTS (MAX_ANALOG_INPUTS + MAX_DIGITAL_INPUTS)

#define VINP0		16
#define VINP1		17
#define VINP2		18
#define VINP3		19
#define VINP4		20
#define VINP5		21
#define VINP6		22
#define VINP7		23

#define MAX_VIRTUAL_INPUTS 8

#define CH1		0		//Mapped to A
#define CH2		1		//Mapped to E
#define CH3		2		//Mapped to T
#define CH4		3		//Mapped to R
#define CH5		4		//Mapped to 5
#define CH6		5		//Mapped to 6
#define CH7		6		//Mapped to 7
#define CH8		7		//Mapped to 8

#define NUM_INPUTS (MAX_ANALOG_INPUTS + MAX_DIGITAL_INPUTS + MAX_VIRTUAL_INPUTS)

#define NUM_OUTPUTS	8
#define SYNC NUM_OUTPUTS
#define NUM_OUTPUTS_INCLUDING_SYNC	(NUM_OUTPUTS + 1)

#define TRIM_UPPER_END 200
#define TRIM_LOWER_END 0
#define TRIM_CENTER 100

#define SIG_TRIM_CH1_PLUS 		0
#define SIG_TRIM_CH1_MINUS 		1
#define SIG_TRIM_CH2_PLUS 		2
#define SIG_TRIM_CH2_MINUS 		3
#define SIG_TRIM_CH3_PLUS 		4
#define SIG_TRIM_CH3_MINUS 		5
#define SIG_TRIM_CH4_PLUS 		6
#define SIG_TRIM_CH4_MINUS 		7

#define PORT_ANALOG	PORTA
#define DDR_ANALOG	DDRA
#define PIN_ANALOG	PINA

#define PORT_TRIM		PORTC
#define DDR_TRIM		DDRC
#define PIN_TRIM		PINC

#define PORT_PPM		PORTD
#define DDR_PPM		DDRD
#define PIN_PPM		PIND

#define PORT_MENU		PORTD
#define DDR_MENU		DDRD
#define PIN_MENU		PIND

#define PORT_SPEAK	PORTD
#define DDR_SPEAK		DDRD


#define SIG_PPM		5
#define SIG_SPEAK	6
#define SIG_MENU_KEY 7


#define HIBYTE(x) (x>>8)
#define LOBYTE(x) (x & 0xFF)
#define HIWORD(x) (x>>4)
#define LOWORD(x) (x & 0xF)


#define ERROR_FACTORY		1



/** radio settings **/
typedef struct {
	uint8_t setup_state;
	uint16_t min_signal_width_us;
	uint16_t max_signal_width_us;
	uint16_t inter_channel_width_us;
	uint16_t frame_width_us;
	uint8_t num_hw_input;		
	uint16_t upper_calibration[MAX_ANALOG_INPUTS];
	uint16_t lower_calibration[MAX_ANALOG_INPUTS];
} SETTINGS, *PSETTINGS;

/** mix **/
typedef struct {
	uint8_t source;			/** source that transform the value, index into the input_hw_controls array **/
	uint8_t target;			/** target that will be changed, values will be first read and then modified based on mplex and rev
										 , always an index in the output_ppm array **/
	uint8_t wt_low;
	uint8_t wt_high;
	
	uint8_t expo_low;
	uint8_t expo_high;
	
	uint8_t rev_mplex;		/** 1b for rev 3b for mplex = add/mult/replace/invert **/
	uint8_t offset;			/** a final offset trim that will be applied **/
} MIX, *PMIX;

/** model **/

#define MAX_LEN_NAME 16
#define MAX_MIXES 32

typedef struct {
	uint8_t uuid[4];					/** 4 bytes of uuid **/
	MIX mixes[MAX_MIXES];				/** array of mixes **/
	uint8_t trims[MAX_ANALOG_INPUTS];	/** array of trims **/
	uint8_t cbSize;						/** size of this model **/
} MODEL, *PMODEL;
				

/** spi communication **/
/** refer to gt-jtx docs for a complete spi dictionary **/
typedef struct {
	uint8_t opcode;
	uint8_t state;
	uint8_t data0;
	uint8_t data1;
	uint16_t result;
} SPITRANSACTION, *PSPITRANSACTION;

enum OPCODE {
   SETTUP = 0x01,		/** set up trim **/
   SETTDN = 0x02,     	/** set down trim **/
   GETT = 0x03,       	/** get trim **/
   SETREV = 0x04,     	/** set signal reverse **/
   GETREV = 0x05,	 	/** get signal reverse **/
   SCUP = 0x06,			/** set calibration upper **/
   GCUP = 0x07,			/** get calibration upper **/
   SCDN = 0x08,			/** set calibration lower **/
   GCDN = 0x09,			/** get calibration lower **/
   SPPMLEN = 0x0A,		/** set PPM length **/
   GPPMLEN = 0x0B,		/** get PPM length **/
   SPPMICL = 0x0C,		/** set PPM Inter-Channel Length, default is 300us **/
   GPPMICL = 0x0D,		/** get PPM Inter-Channel Length **/
   SSTIM = 0x0E,		/** set servo timing **/
   GSTIM = 0x0F,		/** get servo timing **/
   GCV = 0x10,

   /** everything above 0xE0 is control state, 16 signals can be sent back **/

   /** everything above 0xF0 is error state, 16 signals can be sent back **/
   E_BAD_EEPROM = 0xFE,
   E_CALIBRATION_REQUIRED = 0xFD,
   E_NO_MODEL_DEFINED = 0xFC,

   NOP = 0x00,        /** a NOP request will send back the status code to master, if no error, then NOP will be sent back **/
   RESET = 0xFF,	  /** 0xFF is unique code. When gt-jtx gets this signal, it will cause a reset on all values akin to a boot**/
};

enum STATE {
   WAIT_RESET  = 0x00,
   WAIT_OPCODE = 0x01,
   WAIT_HIBYTE = 0x02,
   WAIT_LOBYTE = 0x03,
};

typedef struct {
	uint16_t hw_controls[NUM_PHYSICAL_INPUTS]; /** stores the sensor values, pots or switches **/
} INPUT, *PINPUT;

typedef struct {
	uint16_t ppm[NUM_OUTPUTS_INCLUDING_SYNC];		/** stores the final output ppm sent to the rf module **/

} OUTPUT, *POUTPUT;

typedef struct {
	INPUT input;
	OUTPUT output;

	uint16_t 	signal_traversal_us;
	uint16_t 	mid_signal_width_us;
	uint16_t 	sync_signal_width_us;
	uint8_t 	error;			/** startup errors **/
	uint8_t 	channel;
	uint8_t 	idx;
   uint16_t test;

	SPITRANSACTION transaction;

	/** from here on everything will be serialized to eeprom **/
	SETTINGS settings;			/** serialized to eeprom **/
	MODEL model;				/** serialized to eeprom **/
} RUNTIME, *PRUNTIME;


volatile RUNTIME runtime;


/***************************************** Function Declarations *****************************************/
uint16_t read_analog(uint8_t);
uint16_t micros_to_ticks(uint16_t);
uint8_t get_key_pressed(uint8_t port, uint8_t key);
void process_key_inputs(void);

void reset(void);
void setup_hardware(void);
void read_ad_channel_value(uint8_t);
void read_switch(uint8_t ch, uint8_t port, uint8_t pin);
void calculate_signal_params(void);

void increment_trim(uint8_t channel);
void decrement_trim(uint8_t channel);

void calibrate_channel(uint8_t channel);

void memset16(uint16_t* array, uint16_t value, uint8_t size);
void model_save_trim(uint8_t channel);



/***************************************** Business Objects *****************************************/

void runtime_new (uint8_t debug);

void model_write_to_eeprom(PMODEL);
void model_read_from_eeprom(PMODEL);

void settings_write_to_eeprom(PSETTINGS);
void settings_read_from_eeprom(PSETTINGS);

void calibration_write_to_eeprom(void);
void calibration_read_to_eeprom(void);


/***************************************** Interrupt Declarations *****************************************/
ISR(SPI_STC_vect);     	/**SPI byte received **/
ISR(TIMER1_COMPA_vect); /**PPM time elapsed **/


/************************************MAIN Routine *****************************************
*/

int main(void){
	
	runtime_new(1);                        	
	setup_hardware();
	calculate_signal_params();	
	reset();
	/**Enable global interrupts **/
	sei();
   		/** start our timer **/
	TIMSK |= (1<<OCIE1A);
			/** start the adc **/
	ADCSRA |= (1<<ADSC);

	while(1){
		/** read analog inputs **/
		read_ad_channel_value(INP1);
		read_ad_channel_value(INP2);
		read_ad_channel_value(INP3);
		read_ad_channel_value(INP4);
		read_ad_channel_value(INP5);
		read_ad_channel_value(INP6);
		read_ad_channel_value(INP7);
		read_ad_channel_value(INP8);

		/** read digital inputs **/
		read_switch(INP9, PORTD, PIN4);
		read_switch(INP10, PORTD, PIN6);
		read_switch(INP11, PORTD, PIN7);
		read_switch(INP12, PORTB, PIN0);
		read_switch(INP13, PORTB, PIN1);
		read_switch(INP14, PORTB, PIN2);
		read_switch(INP15, PORTB, PIN3);
		read_switch(INP16, PORTB, PIN4);

		/** apply the mixes **/
		uint8_t idx_mixes = -1;
		while(++idx_mixes < MAX_MIXES){
				mix_apply_transform(&(runtime.model.mixes[idx_mixes]));
		};
	}
};

/**************************************** get_key_pressed *****************************
** This method checks to see if a key has been pressed on a port.
** debounce is included
**/
uint8_t get_key_pressed(uint8_t port, uint8_t key){
	if(((~port) & (1 << key)) == (1 << key))	
	{
		_delay_ms(1);	/** get rid of keybounce **/
		return (((~port) & (1 << key)) == (1 << key));
	}	
	return 0x00;
};


/**************************************** calibrate_channel *****************************
** This method keeps on updating the values if the calibration settings of a channel
** call the method in a loop
**/
void calibrate_channel(uint8_t ch){
	uint16_t calibration = read_analog(ch);		
	if(runtime.settings.upper_calibration[ch] < calibration)
		runtime.settings.upper_calibration[ch] = calibration;
	if(runtime.settings.lower_calibration[ch] > calibration)
		runtime.settings.lower_calibration[ch] = calibration;
}

/**************************************** increment_trim *****************************
** This method increments the trim values of a channel and clamps them between the min and max
** trim values
**/
void increment_trim(uint8_t ch){
	if(++(runtime.model.trims[ch]) > TRIM_UPPER_END){
		(runtime.model.trims[ch]) = TRIM_UPPER_END;
	}
	model_save_trim(ch);
}

/**************************************** decrement_trim *****************************
** This method increments the trim values of a channel and clamps them between the min and max
** trim values
**/
void decrement_trim(uint8_t ch){
	if(runtime.model.trims[ch] > 0 && --runtime.model.trims[ch]<= TRIM_LOWER_END){
		runtime.model.trims[ch] = TRIM_LOWER_END;
	}
	model_save_trim(ch);
}


void model_save_trim(uint8_t channel) {

}


/**************************************** read_ad_channel_value *****************************
** This method reads up the analog value of a channel to the ppm array
** the first 8 channels can have either analog or digital values.
** the next 8 channels can only have digital values.
** analog or digital depends on whether one puts a POT ot a SPDT switch on that channel
**/
void read_ad_channel_value(uint8_t ch){
	uint16_t value = read_analog(ch);
	
	float calibratedChannelRange = runtime.settings.upper_calibration[ch] - runtime.settings.lower_calibration[ch];
	float stickMoveRatio = (value - runtime.settings.lower_calibration[ch])/calibratedChannelRange;
	
	runtime.input.hw_controls[ch] = runtime.settings.min_signal_width_us + ((stickMoveRatio * (float)runtime.signal_traversal_us)) + runtime.model.trims[ch];
}

/**************************************** read_switch *****************************
** This method reads up the digital value of a channel (8-15) to the switches variable
** on these inputs, only a SPDT will work
**/
void read_switch(uint8_t ch, uint8_t port, uint8_t pin){
	
	volatile uint8_t value = get_key_pressed(port, pin);
	//volatile uint8_t value = (get_key_pressed(port, pin) ^ ((reverse & mask) == mask));  /** reverse is not a mixes feature. program it there **/

	runtime.input.hw_controls[ch] = runtime.settings.min_signal_width_us + (value * (float)runtime.signal_traversal_us);
}

/**************************************** micros_to_ticks *****************************
** Converts the values from microseconds to ticks based on the processor clock
**/
uint16_t micros_to_ticks(uint16_t value){
	return (value * ((F_CPU/1000)/1000));
};

/**************************************** calculate_signal_params *****************************
** Calculates the signal limits and other values used in deciding the final ppm signal
**/
void calculate_signal_params(){

	runtime.mid_signal_width_us = ((runtime.settings.min_signal_width_us + runtime.settings.max_signal_width_us)/2) + TRIM_CENTER;
	runtime.sync_signal_width_us = (runtime.settings.frame_width_us - (NUM_OUTPUTS * (runtime.mid_signal_width_us + runtime.settings.inter_channel_width_us))); /**whatever is left **/
	runtime.signal_traversal_us = runtime.settings.max_signal_width_us - runtime.settings.min_signal_width_us;
};


/***************************************** METHOD setupHardware ****************************************
	* Sets up the hardware, sets up the ports, ppm counters, adc and spi
*/

void setup_hardware(){

	/** setup the SPI Slave **/
	/** Port B has the MISO/MOSI pins. Setup MOSI as input **/
	runtime.transaction.state = WAIT_OPCODE;
	DDRB = (1<<PB6);	/**Setup MISO as output */
	SPCR = (1<<SPE) | (1<<SPIE) | (1<<SPR0) | (1<<SPR1)| (1<<CPOL);	/** enable SPI **/
	SPDR = 0xFF;
	sei();

	/** Analog Inputs**/
	DDR_ANALOG = 0x00;						
	PORT_ANALOG = 0x00;				/**Deactivate any pull ups **/
											/**
											 ** PC0 = AIL Input
											 ** PC1 = ELE Input
											 ** PC2 = THR Input
											 ** PC3 = RUD Input
											 ** PC4 = CH5 Input
											 ** PC5 - CH6 Input
											 ** PC6 - CH7 Input
											 ** PC7 - Ch8 Input
											**/
 	
 	/** Trim switches **/
 	DDR_TRIM = 0x00;
 	PORT_TRIM = 0xFF;					/**Activate all pull ups on Port B **/ 	
 	
 	
 	/**PORTC is LCD_DATA, let the lcd library take care of it **/
 	
 	/** PORTD has D:0-D:4 for LCD_CTRL, make D5 (PPM), D6 (SPEAKER), D7 (MENU) as output pins **/
 	DDR_MENU &= ~(1 << SIG_MENU_KEY);					/** D:7 is MENU KEY = 0**/
 	PORT_MENU |= (1 << SIG_MENU_KEY);
  	DDR_SPEAK |= (1 << SIG_SPEAK);						/** D:6 is SPEAKER = 1**/
 	DDR_PPM |= (1 << SIG_PPM);								/** D:5 is PPM = 1**/
 	
 	
	TCNT1 = 0;
	
	TCCR1B |= (1<<CS10) ;									/** F_CPU - 1Mhz Timebase **/
	TCCR1B	|=	(1<<WGM12);									/** CTC Mode**/

	TCCR1A |= (1<<COM1A0);									/** hardware ctc **/
	
	ADMUX |= (1<<REFS0);				
	ADCSRA|= (1<<ADPS2) | (1<<ADPS1) | (1<<ADPS0);	/**F_CPU/64 Prescalar **/
	ADCSRA |= (1<<ADEN); 									/** enable the ADC **/

};


uint16_t read_analog(uint8_t ch){
	ch = ch & 0x07;					/** zero out all bits except last three for limiting channel **/
	ADMUX &=0xE0;								/**reset channel selection **/
	ADMUX |=ch;									/**select the requested channel **/
	ADCSRA |= (1<<ADSC);
	while(!(ADCSRA & (1<<ADIF)));
	ADCSRA|= (1<<ADIF);
	return (ADC);
};

/***************************************** METHOD reset ****************************************
* resets all servos to go to center of signal
**/

void reset(){
	/** create input objects **/
	uint8_t idx = -1;
	
	idx = -1;

	/** set values to match servo spec **/
	memset16(runtime.output.ppm, runtime.mid_signal_width_us, NUM_OUTPUTS_INCLUDING_SYNC);
	/**reset the servo signals **/
	runtime.output.ppm[SYNC] = runtime.sync_signal_width_us;
	/** reset to the first channel **/
	runtime.channel = CH1;
	//OCR1A = micros_to_ticks(runtime.output.ppm[SYNC]);
};

/*****************************************  process_key_inputs ****************************************
	* processes Key inputs on the gt-jtx. These are trim keys only for the gt-jtx-m32
	* most of controls elsewise will be via SPI
	* this needs to be called in a loop for continous polling. Call in the main loop
**/

void process_key_inputs(void){
	if(get_key_pressed(PIN_TRIM, SIG_TRIM_CH1_PLUS)) increment_trim(CH1);
	if(get_key_pressed(PIN_TRIM, SIG_TRIM_CH1_MINUS)) decrement_trim(CH1);
	if(get_key_pressed(PIN_TRIM, SIG_TRIM_CH2_PLUS)) increment_trim(CH2);
	if(get_key_pressed(PIN_TRIM, SIG_TRIM_CH2_MINUS)) decrement_trim(CH2);
	if(get_key_pressed(PIN_TRIM, SIG_TRIM_CH3_PLUS)) increment_trim(CH3);
	if(get_key_pressed(PIN_TRIM, SIG_TRIM_CH3_MINUS)) decrement_trim(CH3);
	if(get_key_pressed(PIN_TRIM, SIG_TRIM_CH4_PLUS)) increment_trim(CH4);
	if(get_key_pressed(PIN_TRIM, SIG_TRIM_CH4_MINUS)) decrement_trim(CH4);
};


/*********************************************** memset16 ***************************************
** used to set values in a 16 bit contigous location
**/
void memset16(uint16_t* a, uint16_t value, uint8_t size){
	volatile uint8_t index = -1;
	while(++index < size){
		a[index] = value;
	};
};



/*****************************************  spi_process_get_message ****************************************
	* processess an SPI message that is required to read something. A byte is called a message
	* this will be executed when the HIBYTE (data0) is received
	* since we need atleast two more bytes to return the result
**/
void spi_process_get_message(void){
 	switch (runtime.transaction.opcode)
	{
		case NOP:
			break;
      case GCV:
        	runtime.transaction.result = (runtime.output.ppm[(runtime.transaction.data0 >> 4)]);
        	break;
   	case GETT:
   			runtime.transaction.result = (runtime.model.trims[(runtime.transaction.data0 >> 4)]);
   			break;
	   case GETREV:
			//runtime.transaction.result = reverse >> (runtime.transaction.data0 >> 4);
	   		break;
		case GCUP:
			runtime.transaction.result = (runtime.settings.lower_calibration[(runtime.transaction.data0 >> 4) - 1]);
			break;
		case GCDN:
			runtime.transaction.result = (runtime.settings.lower_calibration[(runtime.transaction.data0 >> 4) - 1]);
			break;
		case GPPMLEN:
			runtime.transaction.result = runtime.settings.frame_width_us;
			break;
		case GPPMICL:
			runtime.transaction.result = runtime.settings.inter_channel_width_us;
			break;
		case GSTIM:
			runtime.transaction.result = runtime.settings.max_signal_width_us;
			break;
	  	case RESET:
  	     	runtime.transaction.state = WAIT_OPCODE;
  	     	SPDR = 0x00;		
     	   break;
   }
};

/*****************************************  spi_process_set_message ****************************************
	* processess an SPI message that is required to write something. A byte is called a message
	* this will be executed when the RESULT (result) is received on SPI
**/
void spi_process_set_message(void){
 	switch (runtime.transaction.opcode)
	{
		case NOP:
			break;
		case SETTUP:
   		break;
   	case SETTDN:
   		break;
	   case SETREV:
	   	break;
		case SCUP:
			break;
		case SCDN:
			break;
		case SPPMLEN:
			runtime.settings.frame_width_us = (runtime.transaction.data0 << 8) | runtime.transaction.data1;
			calculate_signal_params();
			break;
		case SPPMICL:
			break;
		case SSTIM:
			break;
     	case RESET:
  	     	runtime.transaction.state = WAIT_OPCODE;
  	     	SPDR = 0x00;		
     	   break;
   }
};

void runtime_new (uint8_t debug) {
	/** any error in this function would mean reporting back to client and shutting down the micro
	**/
	memset(&runtime, 0, sizeof(RUNTIME));
	if(debug) {
		/** load debug values for testing **/
		runtime.settings.setup_state = 252;
		runtime.settings.min_signal_width_us = 700;
		runtime.settings.max_signal_width_us = 1700;
		runtime.settings.inter_channel_width_us = 300;
		runtime.settings.frame_width_us = 22500;
		runtime.settings.num_hw_input = 16;		
		memset16(&runtime.settings.upper_calibration, 0, MAX_ANALOG_INPUTS);
		memset16(&runtime.settings.lower_calibration, 1024, MAX_ANALOG_INPUTS);
		/** create a model for testing **/
		eeprom_write_block((uint8_t*)0, &runtime.settings, sizeof(SETTINGS));

	}
	/** load data from eeprom **/
//	eeprom_read_block((uint8_t*)0, &runtime.settings, sizeof(SETTINGS));
}



void mix_apply_transform(PMIX mix)
{
	/** This is the meat of all mixes, every mix when applied will execute this function **/
};


/***************************************** PPM Interrupt ********************************1*********/
ISR(TIMER1_COMPA_vect){
	TIMSK &= ~(1 << OCIE1A);
	if((PIN_PPM & (1 << SIG_PPM)) == (1 << SIG_PPM)){		//If the actual pin is high, we need to set OCR1A to the complementary delay
		OCR1A = micros_to_ticks(runtime.output.ppm[runtime.channel++]);
		if(runtime.channel > SYNC){
			runtime.channel = CH1;
		}
	}		
	else{
		OCR1A = micros_to_ticks(runtime.settings.inter_channel_width_us);
		//OCR1A = micros_to_ticks(runtime.output.ppm[SYNC]);
   }
	TIMSK |= (1<<OCIE1A);
};


/***************************************** SPI Interrupt *****************************************/
ISR(SPI_STC_vect){
	uint8_t data = SPDR;
	if(RESET == data){
	 	SPDR = 0x00;
    	runtime.transaction.state = WAIT_OPCODE;
   	return;
	}
	else{
		switch (runtime.transaction.state){
   		case WAIT_OPCODE:
				runtime.transaction.opcode = data;
				runtime.transaction.state = WAIT_HIBYTE;
	         SPDR = data;     				/**return the opcode as next byte return so master knows what data is being returned**/
	         return ;
	      case WAIT_HIBYTE:
	      	runtime.transaction.data0 = data;	/** data0 MUST have the identifying fields for the opcode **/
	      	runtime.transaction.state = WAIT_LOBYTE;
	      	spi_process_get_message();
				SPDR = HIBYTE(runtime.transaction.result);
				return;
   	  	case WAIT_LOBYTE:
	      	runtime.transaction.data1 = data;
	      	runtime.transaction.state = WAIT_RESET;
      	   SPDR = LOBYTE(runtime.transaction.result);
				return;
   	   case WAIT_RESET:
      	  	SPDR = 0x00;
      	  	spi_process_set_message();
      		runtime.transaction.state = WAIT_OPCODE;
	      	return;
		}
	}
};

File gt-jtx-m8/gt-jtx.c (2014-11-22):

/*
 * gt-jtx.cpp
 *
 * Created: 20-09-2012 15:08:33
 *  Author: Girish Sarwal
 *	 Email: g.sarwal@gmail.com
 *
 */
#ifndef F_CPU
#define F_CPU 1000000UL
#endif

#include <avr/io.h>

#include <util/delay.h>
#include <avr/eeprom.h>
#include <avr/interrupt.h>
#include <math.h>
#include "lcd.h"

#define START_FROM_SYNC_CHANNEL_WIDTH
//#define START_FROM_FIRST_CHANNEL_WIDTH
//#define START_FROM_INTER_CHANNEL_WIDTH

#define USE_LCD_DISPLAY

/** channel mapping to named items **/
#define SYNC	0
#define AIL		1
#define ELE		2
#define THR		3
#define RUD		4
#define FLAPS 	5

#define MAX_CHANNEL FLAPS
#define MAX_ANALOG_CHANNEL RUD
/** Screens -
0 - home screen,
1 - AUX1 - channel settings
MAX_CHANNEL + 1 - Global Settings
MAX_CHANNEL + 2 - Calibration
**/
#define HOME	0
#define SETTINGS1   		MAX_CHANNEL + 1
#define SETTINGS2   		MAX_CHANNEL + 2
#define SAVE_SETTINGS 	MAX_CHANNEL + 3
#define CALIBRATION 		MAX_CHANNEL + 4



#define TRIM_UPPER_END 200
#define TRIM_LOWER_END 0
#define TRIM_CENTER 100

/*#define TRIM_AIL_PLUS 0x01
#define TRIM_AIL_MINUS 0x02
#define TRIM_ELE_PLUS 0x04
#define TRIM_ELE_MINUS 0x08
#define TRIM_THR_PLUS 0x10
#define TRIM_THR_MINUS 0x20
#define TRIM_RUD_PLUS 0x40
#define TRIM_RUD_MINUS 0x80*/

#define TRIM_AIL_PLUS 0x80
#define TRIM_AIL_MINUS 0x08
#define TRIM_ELE_PLUS 0x04
#define TRIM_ELE_MINUS 0x02
#define TRIM_THR_PLUS 0x40
#define TRIM_THR_MINUS 0x20
#define TRIM_RUD_PLUS 0x10
#define TRIM_RUD_MINUS 0x01


#define MAGIC_NUMBER 29543              		
/**DO NOT CHANGE THIS **/

/** EEProm Definitions **/
uint16_t 	EEMEM _eepromOk = MAGIC_NUMBER;			 	
uint8_t 		EEMEM _setupState = 0;					/** Default Setup Status: use to check first time setups **/
uint16_t 	EEMEM _minSignalWidth = 700;
uint16_t 	EEMEM _maxSignalWidth = 1700;
uint16_t 	EEMEM _interChannelWidth = 300;
uint16_t 	EEMEM _frameWidth = 22500;
uint8_t 		EEMEM _trims[MAX_CHANNEL + 1] = {0, 100, 100, 100, 100, 100};
uint8_t 		EEMEM _reverse = 0x00;
uint16_t		EEMEM _calibrationUpper[MAX_ANALOG_CHANNEL];
uint16_t		EEMEM _calibrationLower[MAX_ANALOG_CHANNEL];

uint16_t 	EEPROM_OK;
uint8_t 		SETUP_STATE;
uint16_t 	MAX_SIGNAL_WIDTH;
uint16_t 	MIN_SIGNAL_WIDTH;
uint16_t 	INTER_CHANNEL_WIDTH;
uint16_t 	FRAME_WIDTH;
uint8_t		trims[MAX_CHANNEL + 1];				/** max channels for trims. Although atm only first 4 are useful,
															trims will always range from 0 to 200 points **/
uint8_t		reverse;									/**reverse settings - 0 means not reversed, 1 means channel is reversed 0bXXX00010**/
int8_t 		percent[MAX_CHANNEL + 1];
uint16_t 	calibrationUpper[MAX_ANALOG_CHANNEL];		/** we only need calibration for 1-4 on the sticks **/
uint16_t 	calibrationLower[MAX_ANALOG_CHANNEL];

uint16_t 	SIGNAL_TRAVERSAL;
uint16_t 	MID_SIGNAL_WIDTH;
uint16_t 	SYNC_SIGNAL_WIDTH;
int16_t		ppm[MAX_CHANNEL + 1];	/** accomodate +1 for the sync channel **/

char* 		pszBuffer = 0;
uint8_t		currentScreen = 0;

/** Character strings **/
const char* _strTitle = "#    gt-jtx    #";
const char* _strVersion = "#   m8-ver-1   #";
const char* _strPosVal = "+%d";
const char* _strNegVal = "%d";
const char* _strEepromError = "EEPROM MISSING!";
const char* _strLoadDefEeprom = "Load Def. EEPROM";
const char* _strHome1 = "A:     E:     FL";
const char* _strHome2 = "T:     R:       ";
const char* _strAil = "AIL";
const char* _strEle = "ELE";
const char* _strThr = "THR";
const char* _strRud = "RUD";
const char* _strFlaps = "FLAPS";
const char* _strMs ="ms";
const char* _strTrim = "Trim";
const char* _strState = "St";
const char* _strReverse = "R";
const char* _strYes = "Y";
const char* _strNo = "N";
const char* _strGlobalSettings1Title = "Sig. Width (ms)";
const char* _strGlobalSettings2Title = "IntCh. Frm. (us)";
const char* _strSaveSettings = "SAVE SETTINGS?";
const char* _strMenuToSave = "  Menu to save  ";
const char* _strMoveAetrMinMax = "Mov AETR Min&Max";
const char* _strSeparator = " ";
const char* _strMin = "Min";
const char* _strMax = "Max";

/** Function Declaratons **/
void reset();
void setupHardware();
void getAnalogChannelValue(uint8_t);
void getDigitalChannelValue(uint8_t);
uint16_t readAnalog(uint8_t);
uint16_t micros_to_ticks(uint16_t);
void loadModelSettings();
void incTrim(uint8_t channel);
void decTrim(uint8_t channel);
uint8_t getKeyPressed(uint8_t port, uint8_t key);
void processKeyInputs();
void processDisplay();
void loadParameters();
void calibrateChannel(uint8_t channel);
void loadGlobalSettings();
void saveGlobalSettings();
void saveCalibration();
void checkNavigation();
void saveReverse();

#define STARTADC ADCSRA |= (1<<ADEN) | (1<<ADPS0) | (1<<ADPS1) | (1<<ADPS0) | (1<<ADIE);

static int channel = SYNC;

int main(){
	pszBuffer = malloc(5 * sizeof(char));
	

	/** start routines **/
	loadGlobalSettings();
	setupHardware();


/** Splash Screen **/
   lcd_puts(_strTitle);
	lcd_gotoxy(0, 1);
	lcd_puts(_strVersion);
	_delay_ms(1000);	
	lcd_clrscr();
	
	
	/** check EEPROM Sanity **/
	if(EEPROM_OK != 29543){
		while(1){
			lcd_puts(_strEepromError);
			lcd_gotoxy(0, 1);
			lcd_puts(_strLoadDefEeprom);
		}
	}

	loadDefaultCalibration();								/** Load Default Calibration Settings **/

	if(!(((SETUP_STATE & 0x01) == 0x01)               /** check for Upper Calibration Limits **/
		|| ((SETUP_STATE & 0x02) ==0x02)) ) {			/** check for Lower Calibration Limits **/
			
		currentScreen = CALIBRATION;							/** something is not set,
																		we will start with the calibration screen **/
	}
	else{
		loadCalibration();
		currentScreen = HOME;
	}
	
	loadParameters();
	loadModelSettings();	
	reset();

	/**Enable global interrupts **/
	sei();

	/** start our timer **/
	TIMSK |= (1<<OCIE1A);
	
	/** start the adc **/
	ADCSRA |= (1<<ADSC);

	while(1){
		/**read pot inputs first of all
		TODO: Do this on a timer and ISR**/
		getAnalogChannelValue(AIL);
		getAnalogChannelValue(ELE);
		getAnalogChannelValue(THR);
		getAnalogChannelValue(RUD);
		
		getDigitalChannelValue(FLAPS);

		processKeyInputs();
		processDisplay();
	}
};


uint8_t getKeyPressed(uint8_t port, uint8_t key){
	if(((~port) & key) == key)	
	{
		_delay_ms(1);	/** get rid of keybounce **/
		return (((~port) & key) == key);
	}	
	return 0x00;
}
void calibrateChannel(uint8_t ch)
{
	uint16_t calibration = readAnalog(ch);
	if(calibrationUpper[ch - 1] < calibration)
		calibrationUpper[ch - 1] = calibration;
	if(calibrationLower[ch - 1] > calibration)
		calibrationLower[ch - 1] = calibration;
}

void incTrim(uint8_t ch){
	if(++trims[ch] > TRIM_UPPER_END){
		trims[ch] = TRIM_UPPER_END;
	}
	eeprom_write_byte(&_trims[ch], trims[ch]);
}

void decTrim(uint8_t ch){
	if(trims[ch] > 0 && --trims[ch]<= TRIM_LOWER_END){
		trims[ch] = TRIM_LOWER_END;
	}
	eeprom_write_byte(&_trims[ch], trims[ch]);
}
void saveReverse(){
	eeprom_write_byte(&_reverse, reverse);
}
void checkNavigation(){
	if(getKeyPressed(PIND, TRIM_AIL_PLUS)) { _delay_ms(250); currentScreen++; }
	if(getKeyPressed(PIND, TRIM_AIL_MINUS)) { _delay_ms(250); currentScreen--; }
}
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

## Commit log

2012-09-20 SYNC: attempted to add a timer
2012-09-21 updated to generate a 22ms timer for rc frame on a 1mhz clock
2012-09-24 successfully getting a configurable timed pulse for rc frame. This needs to be moved onto the hardware pin now
2012-10-03 added input from ADC pins (port A) on atmega 8
2012-10-30 added lcd support for 16x2 lcd files added lcd.c, lcd.h channel values for AIL, ELE, THR and RUD shown on display now..values will range between 500 ms and 1500 ms (signal time for the servos)
2012-10-31 updated to output correct RC frame, needs to be verified against a suitable hardware LCD display updated to show percent movements on sticks (between -100 and 100) updated to run on 16 MHz timebase u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
    [gt-jtx.c]
2012-11-16 added USE_LCD_DISPLAY flag to conditional compile for devices without LCD
2012-12-11 added eagle schematic for main board. This is still not complete. Please consider future versions.
    [gt-jtx.brd, gt-jtx.sch]
2012-12-13 gt-jtx now has a board layout and a schematic.
    [gt-jtx.brd, gt-jtx.sch]
2012-12-23 Added ISCP pads on board for ATmega8 programming. Increased Route width for better transfer of toner to PCB. Routes are now on bottom layer so no need to mirror image for printing
    [gt-jtx.brd, gt-jtx.sch]
2012-12-24 changed layer to use top layer.
    [gt-jtx.brd]
2013-01-05 increased track width wherever possible to reduces chance of undercutting while etching. added necking in some areas of pcb
    [gt-jtx.brd]
2013-01-23 added functionality to read from eeprom added calibaration and setting screen (both non working) changed navigation to use menu button
2013-01-25 PARTIAL CHECKIN **CONSIDER FUTURE CHECKINS *** added calibration code added eeprom write for calibration removed a couple of useless function optimized
2013-01-26 Added scripts for erasing chip, flashing chip and flashing eeprom fixed percentage calculation problem
    [gt-jtx.c]
2013-01-28 removed useless pro file from hardware/gt-jtx-breakout.pro added sch and brd files for breakout board
    [gt-jtx-breakout.brd, gt-jtx-breakout.sch]
2013-02-11 Added Build Photos Added Format changes to code Fixed display issues Added trim control setting via navigation buttons
    [gt-jtx.c]
2013-02-11 Project Reorganization
    [gt-jtx-breakout-genius-ms3d.brd, gt-jtx-breakout-genius-ms3d.sch, gt-jtx-m16-ver1.0.brd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]
2013-02-14 fixed makefile added code to reverse channels added flaps button to vmlab project file
    [gt-jtx.c]
2013-02-21 fixe ppm stream for 8 channels
    [gt-jtx.c]
2013-02-27 added speaker and switch ports changed ppm pin to PD5
    [gt-jtx-m32-ver1.0.brd, gt-jtx-m32-ver1.0.sch]
2013-02-27 fixed some of the hardware design
    [gt-jtx-m32-ver1.0.brd, gt-jtx-m32-ver1.0.sch]
2013-03-30 added serial protocol to hardware spec
    [gt-jtx serial protocol.xlsx]
2015-03-02 PARTIAL CHECKIN: fixed problems in m32 version
    [gt-jtx.c]
2015-03-09 added branches which were not moved during git conversion
    [gt-jtx serial protocol.xlsx, gt-jtx-breakout-genius-ms3d.brd, gt-jtx-breakout-genius-ms3d.sch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]
2015-03-11 updated serial protocol for comms
    [gt-jtx serial protocol.xls, gt-jtx serial protocol.xlsx]
2015-12-26 changed pin header to 3x2 instead of 1x6 for accomodating a 6 pin isp. correctec pin configurations
    [gt-jtx-m32-ver1.0.brd, gt-jtx-m32-ver1.0.sch]
2015-12-26 cleaned up directory structure
    [gt-jtx serial protocol.xls, gt-jtx serial protocol.xlsx, gt-jtx-breakout-genius-ms3d.brd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]
2016-07-21 moved helper tools to the correct folder
    [main.c]
2016-07-22 pin numbers are now added as defines
2016-07-22 fixed constant name change for successful build
    [gt-jtx.c]
2016-10-21 fixed ppm signal as per new code
    [gt-jtx.c]
2016-10-21 fixed bug with input no mapping to output correctly
    [gt-jtx.c]
2016-10-26 added hardware schematic png
2017-05-04 added designs for quick build 2560 opentx
    [KS108(fr).xls, MEGA2560_PinMapping.xls, gt-jtx-2560.brd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]
2017-05-25 added new files
    [MEGA2560.sch, MEGA2560_Listing.xls, gt-jtx-2560.brd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]
2017-09-07 added case design, changed the schematic for lcd
    [KS108(fr).xls, gt-jtx-2560.brd, gt-jtx-2560.dxf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]
2018-05-09 fixed LCD connections and added connector for contrast adjustment
    [gt-jtx-2560.brd, gt-jtx-2560.dxf, gt-jtx-2560.sch]
2018-05-14 added sim connector
    [gt-jtx-2560.brd, gt-jtx-2560.sch]

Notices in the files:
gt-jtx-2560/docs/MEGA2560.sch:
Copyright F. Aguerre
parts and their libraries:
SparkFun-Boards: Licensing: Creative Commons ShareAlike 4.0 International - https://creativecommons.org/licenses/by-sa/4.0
